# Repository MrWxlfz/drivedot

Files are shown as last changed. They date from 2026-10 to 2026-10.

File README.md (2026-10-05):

# DriveDot

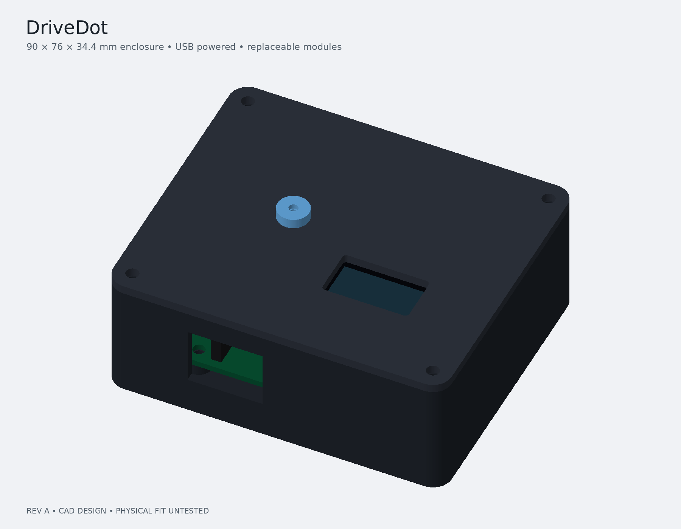
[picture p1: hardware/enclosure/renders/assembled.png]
DriveDot revision A enclosure render


*revision a CAD render — this hasn't been printed or built yet!!!!1*

a little dashboard gadget that tells you how smooth your driving is.

drivedot is an ESP32-S3 with an IMU and a tiny OLED. it reads acceleration, braking, and cornering, draws a live g-force dot on the screen, and gives you a summary when the drive ends. runs off usb, doesn't touch the car's electronics at all.

i'm learning to drive, so i wanted my first hardware project to be something i'd actually use. it's my warm-up project for hack club half-life.

## where it's at

revision a has an actual schematic, routed carrier pcb, printable case and firmware. i used ai to help create these files. the source, exports and checks are here so i can review them, make changes and build the prototype.

- **designed:** 60 × 40 mm, two-layer carrier pcb with XIAO sockets, screen/sensor headers and a button
- **modeled:** screw-fastened case, screen clamp, flat sensor cradle and button plunger
- **implemented:** standalone button controls, calibration, live display, session summary and usb csv
- **checked:** schematic/pcb rules and portable motion, button and calibration tests; see [validation](docs/validation.md)
- **still to do:** measure the real modules, confirm the full cost, print, solder, bench-test and record the results
- **planned:** a small ws2812 rgb led strip that goes green → yellow → red as the forces get harsher. it isn't on the revision a pcb or in the case cad yet, so it's not in the parts list

no physical fit test or road test yet, so no accuracy claims from me. the half life parts list is at about $63.99 for tier 2 ($65): digikey and amazon parts, pcbs from jlcpcb, the seven-part enclosure printed by jlc3dp in 9600 resin, screws from bolt depot, plus shipping, tariffs and a tax ceiling. bolt depot's shipping and soldering supplies aren't in that total, and tax and the final pcb order total are estimates until checkout. 9600 resin softens at about 56 °c, so the first print is a fit test only and not something to leave on a hot dash. nothing has been ordered yet. the parts research and pricing were done with claude.

## open the design

| what | files |
| --- | --- |
| schematic, routed board and fabrication exports | [KiCad project](hardware/pcb/README.md) |
| printable parts, editable CAD, STEP and renders | [enclosure](hardware/enclosure/README.md) |
| parts and required quantities | [selected parts](hardware/parts.md) · [planning BOM](hardware/bom.csv) |
| putting it together | [assembly guide](docs/assembly.md) · [wiring](hardware/wiring.md) |
| firmware and controls | [firmware setup](docs/firmware.md) |
| what's checked and what still needs testing | [validation](docs/validation.md) · [build plan](docs/build-plan.md) |

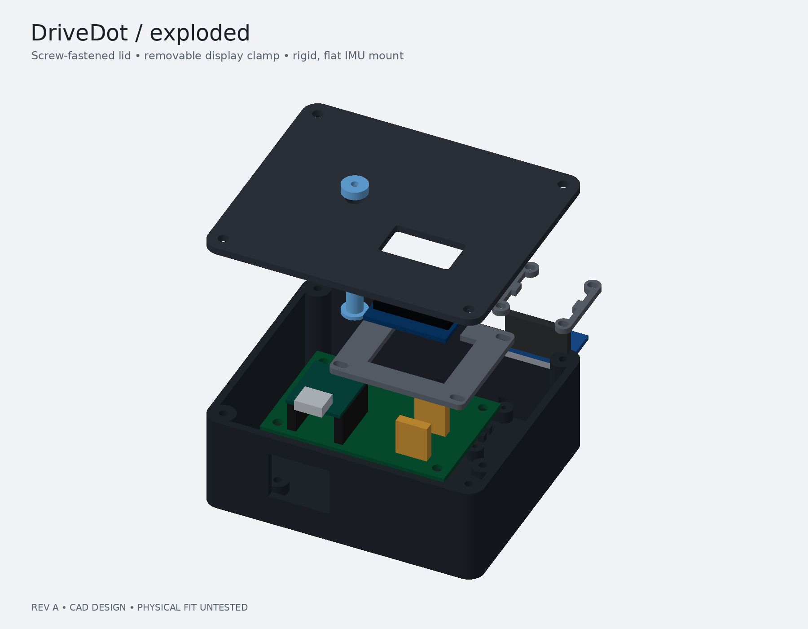
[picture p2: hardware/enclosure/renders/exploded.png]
DriveDot exploded CAD assembly


*exploded CAD view. the screen and sensor connect with short wires; their modeled envelopes still need checking against the received parts.*

## version 1

- Seeed Studio XIAO ESP32S3, GY-521 MPU6050 and 128 × 64 SSD1306 OLED
- hold the button for 1.5 seconds, then release to calibrate while parked and still
- short press/release to start or end a session
- live forward/lateral acceleration and a g-force dot
- summary with peak g and sustained-event counts
- csv over usb serial for checking the numbers

the score is a rough smoothness thing, not a safety grade. hills, bumps, sensor drift, and a shifted mounting angle all mess it up. check the summary while parked. the live feedback is really for a passenger during testing. mount it solid, flat, out of your line of sight and away from airbags.

## running it

1. read the [assembly guide](docs/assembly.md), [schematic notes](docs/first-schematic.md) and [wiring](hardware/wiring.md).
2. open `firmware/` in VS Code with PlatformIO. the selected board is `seeed_xiao_esp32s3`.
3. build and upload through the XIAO's USB-C port with a data cable:

```sh
cd firmware
pio run
pio run --target upload
pio device monitor
```

4. mount the sensor flat and keep it still. hold the button for 1.5 seconds and release when prompted. after calibration, tap to start and tap again to end.
5. serial commands also work: `c` calibrates, `n` starts and `e` ends. see [firmware setup](docs/firmware.md) for errors and limitations.

to run the logic tests without a microcontroller:

```sh
python3 scripts/test.py
```

## license

MIT. see [LICENSE](LICENSE).

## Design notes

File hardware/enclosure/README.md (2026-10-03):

# DriveDot enclosure — revision A

A dimensioned CAD design with seven printable solids, STEP files and generated images. **It has not been printed or physically fitted.** The checks in [validation.json](validation.json) cover the actual CAD/STL geometry against simplified electronic envelopes, not the dimensions of purchased modules.

Assembled CAD

Exploded CAD

The screw-fastened case holds the carrier on four standoffs. A removable frame clamps the OLED into the lid; separate edge clamps hold the IMU flat in the base. A guided plunger and separately screwed cap operate the PCB switch with a travel stop. OLED and IMU mounting holes are not assumed.

## Files and regeneration

- [Editable CadQuery source](../../scripts/generate_enclosure.py)
- [STEP assembly](step/drivedot-assembly.step); individual parts also in `step/`
- [Dimension drawing](dimensions.svg)
- [Body STL](stl/body.stl), [lid STL](stl/lid.stl), [plunger STL](stl/button-plunger.stl), [cap STL](stl/button-cap.stl), [OLED clamp STL](stl/oled-clamp.stl), [left IMU clamp STL](stl/imu-clamp-left.stl), [right IMU clamp STL](stl/imu-clamp-right.stl)
- [Validation report](validation.json)

STLs are already placed on the print bed. Lid and button cap are inverted; all others rest on their lowest flat face. STEP parts retain assembly coordinates. The generated `exports/` meshes are temporary renderer inputs and are omitted from published files.

With Python packages `cadquery==2.7.0`, `vtk`, `numpy` and `Pillow`, run from the repository root:

```sh
python scripts/generate_enclosure.py
```

The source exports CAD/meshes, checks solid validity, checks printed-part intersections and selected electronic keepouts, checks STL boundary/nonmanifold edges, and renders with a CPU depth buffer. No X server is needed. Case width/depth/height/lid thickness, OLED position/PCB size, and switch height are primary parameters. Other dimensions are recorded in the manifest or beside their CAD features. Changing the carrier layout, stack heights, module thicknesses or sensor orientation requires updating associated features and envelopes together. This is not a universal module adapter. The reference drawing must be revised after dimensional changes.

## Mechanical contract

All dimensions are mm. Origin: outside front-left corner; +Y toward the back, +Z upward. Front is the USB side. Vehicle installation must follow verified IMU axes, rather than assuming case axes equal sensor axes.

| Feature | Revision A geometry |
|---|---|
| Case envelope | 90 × 76 × 34.4; button cap reaches Z = 37.65, excluding screw head |
| Walls and floor | 2.4; outside corner radius 5 |
| Lid location | 2-deep lip, nominal 0.30 side gap |
| Lid screws | (5,5), (85,5), (85,71), (5,71); 3.4 clearance |
| Carrier | 60 × 40 × 1.6; lower-left (15,9), bottom Z = 6.0 |
| Carrier holes | (19,13), (71,13), (71,45), (19,45); 3.2 PCB holes |
| USB opening | X = 22…42, Z = 10…26, through front wall |
| OLED PCB | 27 × 25 × 1.6, centre (60,26), bottom Z = 27.6 |
| OLED glass assumption | 24.7 × 16.5 × 2.4, centred on PCB; top Z = 31.6 |
| Screen window | 23.0 × 13.2, centre (60,26); active area assumed 21.744 × 10.864 |
| OLED rear header | 10.16 × 2.54 × 12 downward keepout, centre (60,37.23), Z = 15.6…27.6 |
| IMU PCB | 20 × 15 × 1.6, centre (55,62), bottom Z = 4.8 |
| IMU header | 20.32 × 2.54 × 12 upward keepout, centre (55,55.77), starts Z = 6.4 |
| IMU solder tails | Trim to at most 2.2 below PCB (prefer 2.0); keepout Z = 2.6…4.8 |
| Switch | Centre (32,39); actuator nominally 5.0 above carrier top |
| Plunger | 5.2 shaft in 5.8 bore; 0.20 initial actuator gap |
| Travel stop | Cap stops after 0.45 downward travel, giving nominal 0.25 switch compression |

The XIAO socket plus male spacer is modelled as an 11.0-high stack, plus 1.2 board and 3.5 USB shell. Its top reaches Z = 23.3. **These are estimates:** allow at least 16 above the carrier and measure the purchased sockets, pins and USB plug. The access opening is deliberately broad. Connector and antenna geometry are not vendor CAD.

The OLED frame bears on a 1 mm PCB perimeter and four nominally clear 1.4 × 1.4 PCB corners. Its central rear notch clears the header and wire harness. Put the OLED header toward +Y; a front-facing tall header would clash with the carrier connectors. If this rotates the displayed image, configure firmware rotation after testing. Measure the actual active-area offset and glass envelope before printing the lid. The glass sits 0.4 below the lid; the PCB is held between stops and frame.

IMU clamps contact only 0.8 mm of each side at its middle, leaving the 8-pin header edge exposed. The four underside support pads are beneath these middle contacts, away from header solder. The header faces −Y in this model. Verify all board margins are free of components and solder before tightening; move the pads in CAD if necessary. Keep the IMU rigid and horizontal.

## Fasteners and printing

| Fastener | Quantity | Purpose |
|---|---:|---|
| M3 × 10 | 4 | Lid |
| M3 × 6 | 4 | Carrier |
| M2 × 6 | 4 | OLED clamp |
| M2 × 6 | 4 | IMU clamps |
| M2 × 6 | 1 | Button cap |

These are required fasteners, not sourced purchases or verified prices. Printed pilots are 2.6 for M3 and 1.7 for M2. Test a coupon and ream/tap to suit the printer and screws; hand-tighten into plastic. No inserts are required. Use pan or button heads; the holes have no countersinks. Screw heads are not included in CAD collision checks: measure their diameter and height, verify clearance to adjacent parts, and avoid heads that contact electronics.

Start a bench fit prototype with a 0.4 nozzle, 0.2 layers and at least three walls. The body prints upright; the lid and cap print outside face down. The USB roof needs a 20 mm bridge or removable support, and the cap has a shallow socket bridge. Inspect the slicer preview. Printer tolerance and material performance are untested. The slicer determines filament use and time.

Two underside 12 × 52 × 0.6 recesses accept suitable non-slip or fastening material. Select and test a secure mount outside sightlines and airbag paths. Select material for measured cabin temperatures; the design has no automotive environmental qualification.

## Assembly

1. Check prints and clear pilots. Confirm the plunger slides freely. Insert it into the lid from inside, fit the cap outside, and attach with one M2 × 6. Confirm its travel stop and release.
2. Seat the OLED display outward, with the header at the rear notch. Attach its clamp with four M2 × 6. Check the PCB corners seat on stops without loading the glass or components.
3. Seat the IMU on the four base supports. Check trimmed solder-tail clearance, header orientation and clamp contact margins. Attach both rails using four M2 × 6; the board must stay flat without rattling.
4. Mount the carrier with four M3 × 6, fit modules and route wires clear of the button guide. Leave enough slack to open the lid. Measure the actual switch height and adjust the plunger if it differs from 5.0.
5. Dry-fit the lid and test USB insertion and button release. Close with four M3 × 10 only after checking cable and component clearance. Verify sensor axis signs and calibrate on a level bench.

CAD checks do not simulate wires, screw heads, mechanical force, print tolerance, thermal performance or exact purchased electronics. Physical measurements and a bench fit remain required before treating this as a fabrication-ready design.

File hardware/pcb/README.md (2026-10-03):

# DriveDot carrier — revision A

This is an actual two-layer KiCad design with a routed PCB, schematic, Gerbers and drill files. It is **an unbuilt prototype design**. Electrical and design-rule checks pass; received-part fit, assembly, power-up and driving measurements have not been tested.

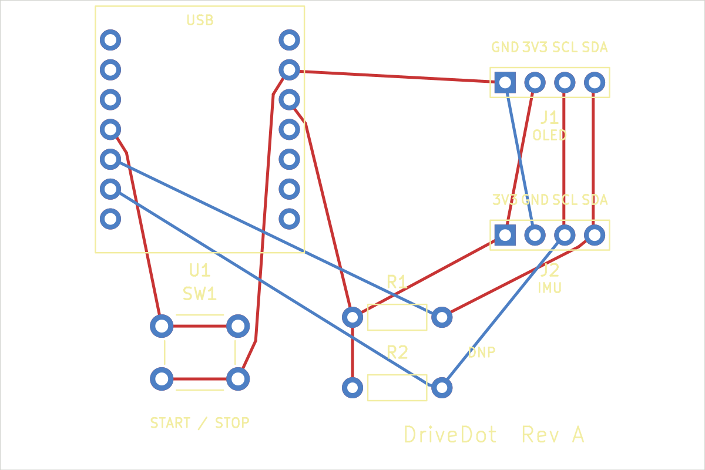
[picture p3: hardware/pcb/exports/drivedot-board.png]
DriveDot PCB: red front copper, blue back copper, yellow silkscreen


## Open the design

Open [`drivedot.kicad_pro`](drivedot.kicad_pro) in **KiCad 9**. The project-local symbols, footprints and library tables are included. There are no library downloads needed to edit this board.

- [Schematic PDF](exports/drivedot-schematic.pdf) · [schematic image](exports/drivedot-schematic.png)
- [Front copper preview](exports/drivedot-front.png) · [back copper preview, mirrored](exports/drivedot-back.png)
- [Schematic source](drivedot.kicad_sch) · [PCB source](drivedot.kicad_pcb)
- [Fabrication exports](fabrication/) · [fabrication ZIP](drivedot-rev-a-gerbers.zip)
- [ERC report](validation/erc.rpt) · [DRC and schematic-parity report](validation/drc.rpt)
- [Footprint evidence and license](SOURCES.md)

## Circuit and assembly

U1 holds the **standard Seeed XIAO ESP32S3**, USB facing the `USB` silkscreen. Solder two 1×7, 2.54 mm male headers to the XIAO and matching female sockets to the carrier. The 15.24 mm spacing between socket rows follows Seeed's official footprint. Socket mounting avoids pressing the XIAO's underside components against this carrier.

The display and GY-521 are mounted separately in the enclosure and joined with short insulated wires. J1 and J2 are **different power orders**. Their pin 1 pads are square. Viewed from the component side, pins increase left to right:

| Carrier pin | J1 → OLED | J2 → GY-521 |
| --- | --- | --- |
| 1 | GND | VCC / 3.3 V |
| 2 | VCC / 3.3 V | GND |
| 3 | SCL | SCL |
| 4 | SDA | SDA |

Connect the other end by the module's printed labels, including when a supplied header orientation differs. U1 D4/GPIO5 supplies SDA, D5/GPIO6 supplies SCL, and D3/GPIO4 reads SW1. Leave the sensor's AD0 low for address `0x68`; the OLED is expected at `0x3C`. The 5 V XIAO header pad is intentionally unconnected.

SW1 is a 6 mm tactile switch with 6.5 × 4.5 mm lead spacing. The two pads along each horizontal row are the same switch terminal. Confirm this with a continuity meter before soldering an alternate switch. Its actuator height must match the enclosure's adjustable button stem.

**R1 and R2 are optional 4.7 kΩ pull-ups and default to DNP (do not populate).** The footprints use 7.62 mm axial lead pitch. Selected modules may already contain pull-ups; adding another pair blindly changes the bus loading. Neither resistor is needed in the default carrier purchase list until the actual modules are inspected.

### Power-up checks

1. Unplug USB. Check socket orientation, continuity, absence of a 3.3 V-to-ground short, and all four harness wires against their labels.
2. Power the XIAO alone first, then connect the modules with USB unplugged. Power comes only from the XIAO USB-C port.
3. Measure the carrier 3.3 V rail and the GY-521's actual regulated sensor rail. The supplier lists 3.3 V VCC operation, but generic GY-521 regulator revisions vary. A dropout-prone module can undervolt the sensor; verify its rail against the actual regulator and MPU6050 specifications.
4. Check idle SDA/SCL voltages and the modules' pull-up supply rails. All bus signals must be compatible with the XIAO's 3.3 V logic. If the breakout revision is incompatible, change the module or design before using it; do not move J2 to 5 V by improvising a wire.
5. Run an I2C scanner, verify `0x68` and `0x3C`, then verify sensor axis directions and the button before closing the case.

Mount the IMU flat and rigidly: X forward, Y left, Z up. Calibration and vehicle motion testing still need to be done. This carrier has no connection to vehicle control or wiring.

## Mechanical interface

Coordinates are millimetres, viewed from above, origin at the carrier's USB-side left corner. Positive X runs right; positive Y runs away from the USB edge.

| Feature | Position / dimensions |
| --- | --- |
| Carrier | 60 × 40 × 1.6 mm |
| Non-plated mounting holes | Ø3.2 mm at (4,4), (56,4), (56,36), (4,36) |
| XIAO centre | (17,11), USB toward negative Y |
| XIAO board envelope | X 8.1–25.9; Y 0.5–21.5 mm |
| XIAO pin rows | X 9.38 / 24.62; first row Y 3.38; 2.54 mm pitch |
| J1 OLED | Pin 1 at (43,7); four pads along +X, 2.54 mm pitch |
| J2 IMU | Pin 1 at (43,20); four pads along +X, 2.54 mm pitch |
| SW1 actuator centre | (17,30) |
| R1 / R2 | Pin 1 at (30,27) / (30,33), 7.62 mm pitch along +X |

Allow up to **16 mm above the carrier** for an ordinary socket, male header, XIAO board and USB connector stack. This is a clearance allowance, not a measured supplied-part height. Check the actual header stack and cable moulding before printing a final enclosure. The USB shell extends approximately 1 mm beyond the carrier's Y=0 edge. The XIAO uses an external U.FL antenna connector; this firmware does not enable radio functions. There is no fictional on-board antenna keepout. If radio functionality is added, the external antenna must be placed and verified separately.

## Fabrication and validation

Suggested prototype fabrication settings: **two-layer FR-4, 1.6 mm, 1 oz copper**, ordinary solder mask, plated component holes and separate non-plated mounting holes. Board dimensions and hole type must be checked in the fabricator's viewer before ordering. The ZIP contains manufacturing files; it is not evidence of assembly or electrical operation.

KiCad **9.0.9** reports **0 ERC violations, 0 DRC violations, 0 unconnected items and 0 schematic-parity issues**, with warnings and exclusions included. No ERC or DRC issues are excluded. The four mechanical holes are intentionally board-only footprints. Tracks are 0.25 mm with a 0.20 mm minimum clearance. There are 30 plated component holes and 4 non-plated mounting holes; this layout needs no vias.

The generator and exports are reproducible:

```bash
/usr/bin/python3 scripts/generate_pcb.py
bash scripts/generate_pcb_exports.sh
```

Run from the repository root with KiCad 9's Python `pcbnew` module and CLI installed. The generator rebuilds sources and can overwrite manual CAD edits. Editing the committed KiCad files directly is also supported; rerun the export script after editing. It removes the previous fabrication ZIP before checking the design, and recreates the ZIP and validation hashes only after checks pass. Install the optional `cairosvg` Python package to refresh PNG previews in the same command; native SVG/PDF exports do not need it. PNG previews are rasterizations of the native SVG exports, not concept artwork. The supplied component and net names are checked against an exported schematic netlist before routing, and KiCad independently checks schematic/PCB parity afterward.

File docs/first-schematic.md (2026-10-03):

# Review the schematic

The revision A source and exports are in [hardware/pcb](../hardware/pcb/README.md). Open the supplied schematic in KiCad and follow these nets before assembling it.

| Net | Connections | Purpose |
| --- | --- | --- |
| +3V3 | XIAO 3V3 to both module connectors | Powers the selected 3.3V-compatible modules |
| GND | XIAO GND, both module connectors and button | Common return |
| SDA | XIAO D4 / GPIO5 to OLED and IMU SDA | I2C data |
| SCL | XIAO D5 / GPIO6 to OLED and IMU SCL | I2C clock |
| BUTTON | XIAO D3 / GPIO4 to normally-open button | Pulls low when pressed; firmware enables an internal pull-up |

The display and sensor connect with short wire harnesses. Their generic breakout footprints are not soldered directly to the carrier: received module sizes and pin orders can differ. Follow each connector's numbered pin labels and the actual breakout silkscreen. The OLED and IMU carrier connectors use different power-pin orders.

The GY-521's AD0 must be low for address `0x68`. Check its existing pull-down; wire AD0 to GND on the module if needed. Unused XDA, XCL and INT pins are left unconnected. The OLED is expected at `0x3C`.

Check both breakouts for I2C pull-ups and supply requirements. Pull-ups must reference 3.3V; do not add extra resistors without checking the combined resistance. Verify the GY-521's regulated sensor rail when supplied with 3.3V, since generic boards use different regulators. Do not compensate by feeding 5V to GPIO-connected pull-ups.

With power disconnected, use a meter to check that the switch closes GPIO4 to GND only when pressed. Check that 3V3 and GND are not shorted, and check each harness end-to-end before connecting it.

The CAD and electrical checks describe the design files. They do not verify soldering, received components or a physical prototype. Record what you inspect and change in your own journal, with the actual time spent.

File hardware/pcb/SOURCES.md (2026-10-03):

# Footprint evidence and authorship

Checked October 2, 2026. The schematic symbols, footprint graphics, routing generator and carrier design in this directory were created for DriveDot with AI assistance. They use the repository's MIT license. No supplier CAD artwork, logo, footprint file or 3D model is redistributed in this directory. Numerical dimensions and electrical connections are taken from the sources below; the vendor names identify compatible purchased parts.

| Source | Used to verify |
| --- | --- |
| [Seeed XIAO ESP32S3 documentation](https://wiki.seeedstudio.com/xiao_esp32s3_getting_started/) | D3/GPIO4, D4/GPIO5/SDA, D5/GPIO6/SCL; 3V3 regulated output; standard board envelope 21 × 17.8 mm; external antenna connector; header assembly |
| [Seeed official XIAO footprint archive](https://files.seeedstudio.com/wiki/XIAO-KiCad-Library/New_XIAO_Series_Footprints.zip), `XIAO-ESP32-S3-DIP.kicad_mod` | Fourteen through-hole centres at ±7.62 mm across rows, 2.54 mm along rows; physical numbering; USB orientation and approximate overhang |
| [ElectroPeak LCD-01-125 OLED](https://electropeak.com/0-96-inch-i2c-oled-display-module-ssd1306) | GND, VCC, SCL, SDA connector mapping; 3.3 V supply option. Module is wired off-board; no assumed module footprint is used |
| [ElectroPeak SEN-03-004 GY-521](https://electropeak.com/gyro-accelerometer-gy521-mpu6050) | VCC/GND/SCL/SDA roles, 3.3 V supply listing, default `0x68` address with AD0 low; listing itself flags generic-board revision variation |
| [Adafruit 367](https://www.adafruit.com/product/367), linked example 6 mm switch datasheet | Nominal 6 mm tactile body; 6.5 × 4.5 mm standard lead arrangement. Received-switch contact pairing and actuator height remain physical checks |
| [KiCad switch footprint source](https://gitlab.com/kicad/libraries/kicad-footprints/-/blob/master/Button_Switch_THT.pretty/SW_PUSH_6mm.kicad_mod) | Independent cross-check of the 6.5 × 4.5 mm pattern and horizontally paired duplicate switch terminals; footprint was redrawn, not copied |

The original Seeed footprint uses a 0.889 mm through-hole drill. DriveDot's independent socket carrier footprint deliberately uses 1.0 mm drills with 1.8 mm pads for standard 0.64 mm square socket leads. Header fit still requires a physical check. Generic off-board modules are connected by their printed labels because variant layouts and header orders differ.

DNP resistor and header footprints use standard 2.54/7.62 mm connector and axial lead pitches, not claims about an unselected vendor part. Matching sockets, wire and any optional resistors need final sourcing. The shared project budget remains unquoted for those items and for PCB delivery.

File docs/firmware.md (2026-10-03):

# Firmware notes

## Setup

Install PlatformIO through its VS Code extension or `python3 -m pip install platformio==6.1.18`. Open the `firmware` folder. The pinned PlatformIO environment targets the standard Seeed Studio XIAO ESP32S3 and uses its USB-C port for power, upload and native USB serial. The selected board manifest enables USB CDC at boot. Use a data-capable cable.

Other S3 variants, flash sizes or native-USB arrangements need matching board settings. Check the vendor documentation; don't copy a generic pin map onto a different board. Update `include/config.h` for different pins and I²C addresses. This selection uses D4/GPIO5 for SDA, D5/GPIO6 for SCL and D3/GPIO4 for the button. If upload cannot find the board, hold BOOT while connecting USB, release it, then retry; see the [manufacturer's guide](https://wiki.seeedstudio.com/xiao_esp32s3_getting_started/).

## Controls

| Input | Behavior |
| --- | --- |
| Hold button for 1.5 seconds, then release | When idle: calibrate after a short settling pause; keep the unit flat and stationary for about 2 seconds |
| Short button press and release | Start or end a session after calibration |
| Long hold during a session | Ignored; release does not end the session |
| Serial `c` | Same calibration while idle; ignored during a session |
| Serial `n` | Start a new session after calibration; ignored during an existing session |
| Serial `e` | End session and retain summary |

At power-up, the OLED prompts `PARK + MOUNT FLAT` / `Hold button 1.5s`. Hold until `RELEASE BUTTON`, release, and keep still. A successful calibration opens the ready screen. Tap to start, then tap to end and view the summary. No computer or serial command is required after uploading firmware.

Calibration is explicit, since power might be connected while the car is moving. Recalibrate while parked whenever you change the mount. A retry clears the previous calibration, so failure cannot silently reuse offsets from a different mounting position. Results are in RAM and disappear on restart.

The 100-sample calibration rejects nonfinite values, obvious motion on any acceleration axis, angular motion, zeroed data, an upside-down sensor and a substantially tilted mount. Defaults require acceleration magnitude 0.8–1.2 g, positive Z at least 0.8 g, horizontal magnitude no more than 0.35 g, gyro magnitude no more than 0.1 rad/s, and variance no more than 0.04 (m/s²)² on each axis. These are provisional bench thresholds, not proof that a vehicle is stationary. The check cannot reliably distinguish steady acceleration from tilt: calibrate only while parked.

The button uses 35 ms debouncing. A long hold consumes the release, preventing calibration from immediately starting a session. A short press acts on release.

## Measurement model

Subtract stationary X/Y offsets, convert m/s² to g using 9.80665, then apply a 120 ms low-pass filter. The baseline remains fixed during a drive so sustained acceleration isn't silently learned away. This is a first prototype: no gyroscope-based attitude compensation, GPS, speed measurement, automatic trip detection or cloud service.

This approach works best with a fixed, flat mounting orientation. Road grade and vehicle pitch/roll alter the gravity projection; changing tilt by hand can look like acceleration. The gyro is used only to help reject motion during calibration.

Events use provisional 0.30 g forward/braking and 0.35 g lateral thresholds, a 300 ms dwell and a 70% reset level. One held excursion produces one event. Smoothness is `100 × (1 − harsh_time / sampled_session_time)`, rounded to an integer. A score exists only after sampling; it isn't validated against driving skill or safety.

The sampling target is 50 Hz and display target 10 Hz, with I²C at 400 kHz. OLED/I²C transfers can lower the effective sampling rate; CSV timestamps are the evidence. Time deltas are taken after completed reads. Loop gaps over 200 ms are excluded from sampled session time and reset pending event dwell. A calibration sample gap over 100 ms rejects that attempt.

## Sensor errors

The pinned [Adafruit MPU6050 2.2.6 source](https://github.com/adafruit/Adafruit_MPU6050/blob/2.2.6/Adafruit_MPU6050.cpp) returns `true` from `getEvent()` even though its underlying burst read does not propagate an I²C error. DriveDot uses Adafruit initialization but reads the 14 sensor bytes directly through `Wire`, checking the address transaction and exact byte count. Conversion uses the selected ±4 g / ±500°/s scales. The range/filter configuration is read back at boot and before calibration.

A failed transaction stops an active session, prints its partial summary to serial, and leaves `SENSOR ERROR` on the OLED; check the connections and restart. This handles observable bus failures, not every sensor failure: a stuck sensor returning plausible bytes, changed configuration mid-session, or a disconnected display may not be detected. Hardware unplug/reconnect behavior has not yet been bench-tested.

CSV columns: `ms,forward_g,lateral_g,score,active`. A score of `-1` means no session samples have been recorded yet. Lines beginning with `#` are messages. When inactive the displayed score belongs to the last session, not current motion. No trip files are stored on-device.

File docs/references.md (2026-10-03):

# References

Primary references for the revision A design and selected hardware:

- [Seeed XIAO ESP32S3 pinout, power and CAD resources](https://wiki.seeedstudio.com/xiao_esp32s3_getting_started/)
- [PlatformIO XIAO ESP32S3 configuration](https://docs.platformio.org/en/latest/boards/espressif32/seeed_xiao_esp32s3.html)
- [Adafruit MPU6050 Arduino guide](https://learn.adafruit.com/mpu6050-6-dof-accelerometer-and-gyro/arduino)
- [Adafruit MPU6050 API](https://adafruit.github.io/Adafruit_MPU6050/html/class_adafruit___m_p_u6050.html)
- [Adafruit SSD1306 source and examples](https://github.com/adafruit/Adafruit_SSD1306)
- [KiCad documentation](https://docs.kicad.org/)
- [Hack Club hardware](https://hardware.hackclub.com/)

The Adafruit guide describes its own breakout. Generic modules need their own schematics and voltage checks. See [selected parts](../hardware/parts.md) for supplier listings and [PCB notes](../hardware/pcb/README.md) for dimensional sources. Funding details come from the user's project screenshot; event rules and eligibility still need checking on the event itself.

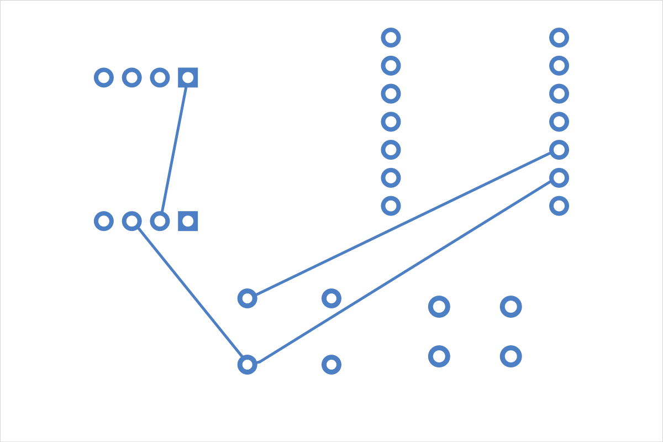
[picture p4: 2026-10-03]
hardware/pcb/exports/drivedot-back.png

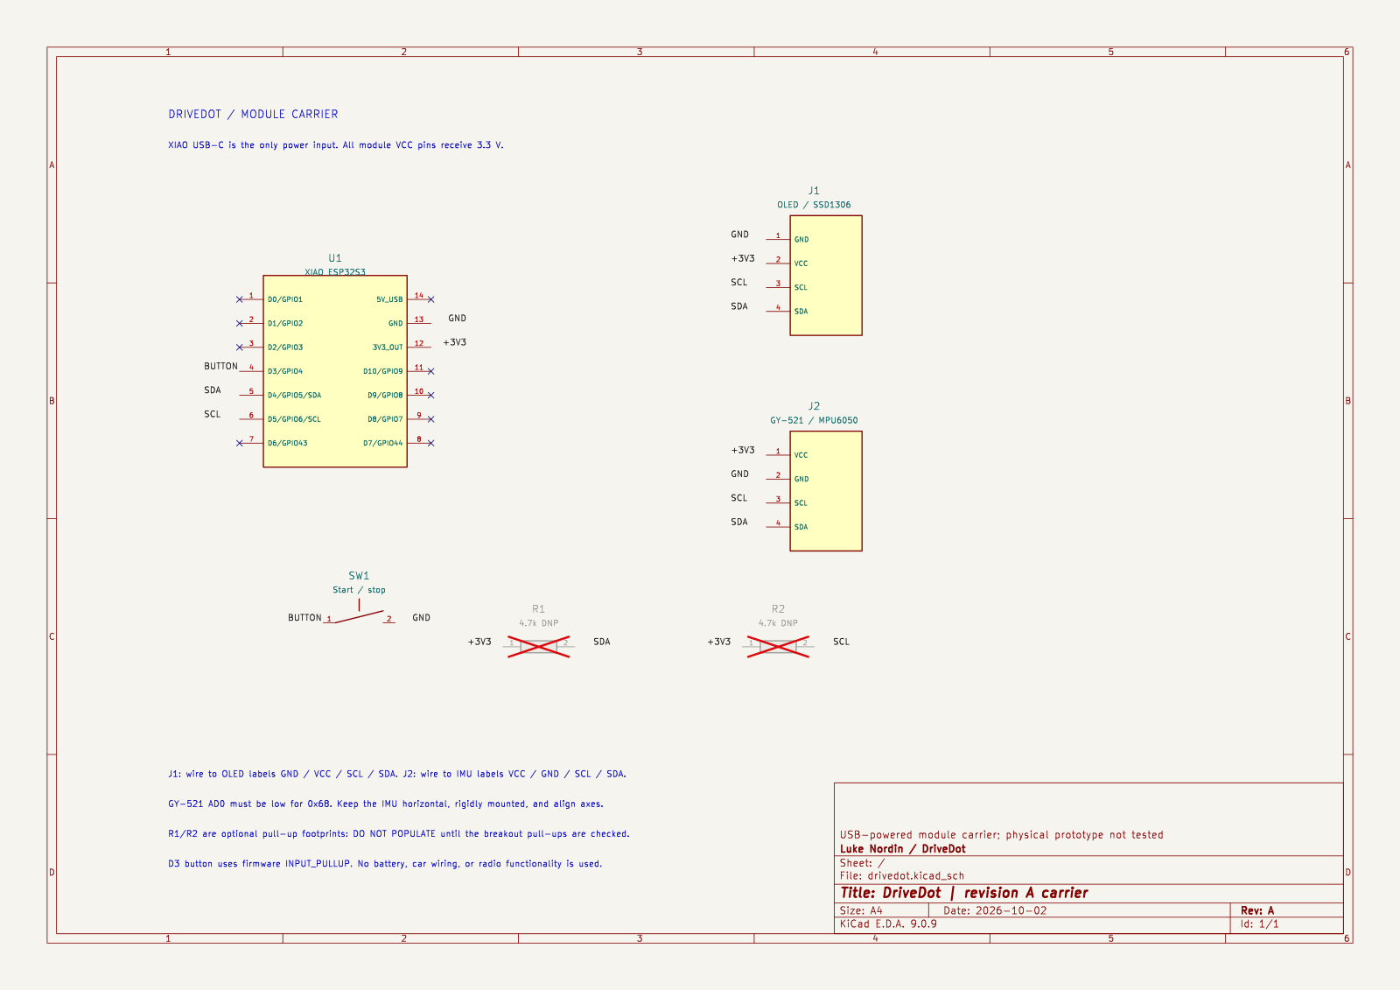
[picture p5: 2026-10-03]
hardware/pcb/exports/drivedot-schematic.png

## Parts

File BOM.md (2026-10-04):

# DriveDot — bill of materials

<!-- Generated by Half Life from project cmurr6oiu00zx01smbi1uyswa. Edits here are overwritten on the next sync. -->
<!-- Generated: 2026-10-04T16:18:33.363Z -->

> [!NOTE]
> This parts list is mirrored from [Half Life](https://halflife.hackclub.com). Editing it here will not change the platform's copy, and the next sync overwrites this file.

| Week | Tier | Parts funding |
| --- | --- | --- |
| Warm-up | Tier 1 | $30.00 |

| Part | What it's for | Qty | Unit | Total | Vendor |
| --- | --- | --- | --- | --- | --- |
| [USB-A to USB-C data cable, 1 m (Cvilux DH-20M50052)](https://www.digikey.com/en/products/detail/cvilux-usa/DH-20M50052/13177409) | Power and programming from the car's USB port | 1 | $1.80 | $1.80 | [DigiKey](https://www.digikey.com/en/products/detail/cvilux-usa/DH-20M50052/13177409) |
| [Seeed Studio XIAO ESP32S3 (113991114)](https://www.digikey.com/en/products/detail/seeed-technology-co-ltd/113991114/19285530) | Main controller (Wi-Fi/BLE ESP32-S3), plugs into the carrier PCB sockets | 1 | $7.49 | $7.49 | [DigiKey](https://www.digikey.com/en/products/detail/seeed-technology-co-ltd/113991114/19285530) |
| [C&K PTS645SL50-2 LFS tactile switch, 6x6 mm](https://www.digikey.com/en/products/detail/c-k/PTS645SL50-2-LFS/1146781) | Start/stop and calibration button on the carrier PCB | 1 | $0.28 | $0.28 | [DigiKey](https://www.digikey.com/en/products/detail/c-k/PTS645SL50-2-LFS/1146781) |
| [Sullins PPTC071LFBN-RC 7-pin female socket strip](https://www.digikey.com/en/products/detail/sullins-connector-solutions/PPTC071LFBN-RC/810146) | Two strips that the XIAO plugs into on the carrier PCB, so it is removable | 2 | $0.58 | $1.16 | [DigiKey](https://www.digikey.com/en/products/detail/sullins-connector-solutions/PPTC071LFBN-RC/810146) |
| [Sullins PRPC036SAAN-RC 36-pin male header strip](https://www.digikey.com/en/products/detail/sullins-connector-solutions/PRPC036SAAN-RC/2775218) | Cut to length for the XIAO pins and the OLED, IMU and carrier connectors | 1 | $0.65 | $0.65 | [DigiKey](https://www.digikey.com/en/products/detail/sullins-connector-solutions/PRPC036SAAN-RC/2775218) |
| [Adafruit 1951 female-to-female jumper wires, 3 in (20 pack)](https://www.digikey.com/en/products/detail/adafruit-industries-llc/1951/6827085) | Short wire harnesses from the carrier PCB to the OLED and the IMU module | 1 | $1.95 | $1.95 | [DigiKey](https://www.digikey.com/en/products/detail/adafruit-industries-llc/1951/6827085) |
| [3M 4026 double-sided mounting square, 3/4 in](https://www.digikey.com/en/products/detail/3m/4026-3-4-X3-4/1818870) | Sticks the enclosure to the dashboard | 2 | $0.36 | $0.72 | [DigiKey](https://www.digikey.com/en/products/detail/3m/4026-3-4-X3-4/1818870) |
| [0.96 in SSD1306 128x64 I2C OLED display module](https://www.amazon.com/dp/B0H6P6N3X7) | Live display: g-force dot, smoothness score and session summary (I2C address 0x3C) | 1 | $5.99 | $5.99 | [Amazon](https://www.amazon.com/dp/B0H6P6N3X7) |
| [GY-521 MPU6050 6-axis accelerometer/gyro module (2-pack)](https://www.amazon.com/dp/B0CYZ7BW1S) | Motion sensor that measures acceleration, braking and cornering (I2C address 0x68). One pack, second sensor is a spare | 1 | $7.98 | $7.98 | [Amazon](https://www.amazon.com/dp/B0CYZ7BW1S) |
| [Custom carrier PCB, 2-layer FR-4, 60 x 40 mm, 1.6 mm (min. order of 5)](https://cart.jlcpcb.com/quote) | Carries the XIAO sockets, OLED and IMU connectors and the button (Rev A gerbers in repo) | 1 | $4.00 | $4.00 | [JLCPCB](https://cart.jlcpcb.com/quote) |
| [BTF-Lighting WS2812B RGB LED strip, 5V, 60 LED/m, 3.28 ft](https://www.amazon.com/dp/B088BRY2SH) | Smoothness light that goes green to yellow to red as forces get harsher (planned add-on, a short cut length is used) | 1 | $7.99 | $7.99 | [Amazon](https://www.amazon.com/dp/B088BRY2SH) |
| **Parts subtotal** | — | — | — | **$40.01** | — |
| **Tax & shipping** | — | — | — | **$16.56** | — |
| **Total** | — | — | — | **$56.57** | — |

**$26.57 over the tier's funding.** Every tier gives a fixed amount for parts, so this needs cutting back or a higher tier.

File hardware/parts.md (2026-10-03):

# Selected parts

Supplier listings checked October 2, 2026. No orders have been placed.

| Part | Exact selection | Buy quantity | Listed USD price | Supplier |
| --- | --- | --- | --- | --- |
| Controller | Seeed Studio XIAO ESP32S3, SKU 113991114, standard unsoldered 1pcs | 1 | $7.49 | [Seeed](https://www.seeedstudio.com/XIAO-ESP32S3-p-5627.html) |
| Motion sensor | GY-521 MPU6050, SEN-03-004 | 1 | $1.96 | [ElectroPeak](https://electropeak.com/gyro-accelerometer-gy521-mpu6050) |
| Screen | 0.96-inch SSD1306 I2C OLED, LCD-01-125; white option preferred | 1 | $1.29 base listing | [ElectroPeak](https://electropeak.com/0-96-inch-i2c-oled-display-module-ssd1306) |
| Button | 6mm through-hole tactile switch, Adafruit product 367 | 1 pack of 20 | $2.50 for the whole pack | [Adafruit](https://www.adafruit.com/product/367) |

These four listings total **$13.24 before shipping, tax or import charges**. Screen option pricing must be confirmed. The full button pack is counted, not a fictional one-button checkout price. If a suitable button is already available or can be bought from another selected supplier, replace that line with the real source and price to avoid a third shipment.

## Budget check

The four core listings total **$13.24**, leaving **$16.76 of a $30 budget** before the carrier, connectors, fasteners, printing, cable, shipping and tax. That remaining amount is not an approved or quoted budget.

Revision A also needs two 1x7 XIAO socket strips, mating male headers, two 1x4 carrier headers, two short four-wire module harnesses, the printed part set, four M3x10 screws, four M3x6 screws and nine M2x6 screws. The exact head types and print details are in the [enclosure guide](enclosure/README.md). Count any supplied or already-owned parts before buying duplicates. The [planning CSV](bom.csv) separates these required quantities from the four priced listings; unquoted cells are intentionally blank.

**The complete Tier 1 budget is not verified.** Previous generic allowances are not supplier quotes for this finished design. Confirm checkout totals and fabrication pricing, including minimum order and pack quantities. Shipping from multiple suppliers may require consolidated sourcing or available supplies to meet the target.

## Why this controller

The XIAO has a compact form factor and a documented pinout and KiCad resources. The firmware now selects `seeed_xiao_esp32s3` and uses D4/GPIO5 for SDA, D5/GPIO6 for SCL and D3/GPIO4 for the button. It replaces the generic DevKitC configuration in the starter.

- [Seeed pinout, power details and CAD resources](https://wiki.seeedstudio.com/xiao_esp32s3_getting_started/)
- [PlatformIO XIAO ESP32S3 board](https://docs.platformio.org/en/latest/boards/espressif32/seeed_xiao_esp32s3.html)

Version 1 remains USB powered. It does not need a battery, Grove base, camera expansion board or RGB strip.

## Before ordering revision A

The carrier uses socket/header footprints, with wired connections to the generic breakouts. Use the module schematics and received board markings. Keep I2C at 3.3V, inspect the GY-521 regulator and pull-ups, check OLED address and pin order, and measure headers and mounting holes. Cheap generic breakouts can differ between batches. Supplier dimensional claims are starting points, not a completed mechanical fit check.

## Half-Life parts entry

Add actual selected purchases to the project's parts form with their vendor URLs and full purchase quantities. Enter shipping/tax separately from checkout quotes. `hardware/bom.csv` is a planning sheet; the event's synced root `BOM.md` should remain managed by the event.

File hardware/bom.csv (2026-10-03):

item | quantity | unit_usd | total_usd | specification | supplier_url | price_status
Seeed Studio XIAO ESP32S3 SKU 113991114 | 1 | 7.49 | 7.49 | standard unsoldered 1pcs version; USB-C; not Sense or Plus | https://www.seeedstudio.com/XIAO-ESP32S3-p-5627.html | listed USD price checked 2026-10-02; checkout not quoted
GY-521 MPU6050 ElectroPeak SEN-03-004 | 1 | 1.96 | 1.96 | I2C; VCC at 3.3V; verify received module | https://electropeak.com/gyro-accelerometer-gy521-mpu6050 | listed USD price checked 2026-10-02; checkout not quoted
SSD1306 I2C OLED ElectroPeak LCD-01-125 | 1 | 1.29 | 1.29 | 128x64; 4-pin I2C; request white option; confirm selected variant price | https://electropeak.com/0-96-inch-i2c-oled-display-module-ssd1306 | listed base USD price checked 2026-10-02; variant checkout not quoted
Adafruit 367 tactile button 20-pack | 1 | 2.50 | 2.50 | one full 20-pack purchase; use one button; 6mm through-hole | https://www.adafruit.com/product/367 | listed USD pack price checked 2026-10-02; checkout not quoted
Optional I2C pull-up resistors R1 R2 | 2 |  |  | 4.7k axial; 7.62mm lead spacing; DO NOT POPULATE unless measured breakout pull-ups require these |  | optional DNP; not included in core parts subtotal
XIAO socket strips | 2 |  |  | 1x7 female 2.54mm pitch; selected stack height must match enclosure |  | unquoted; supplier and purchase pack size pending
XIAO male header strips | 2 |  |  | 1x7 male 2.54mm pitch; may be included with XIAO; verify before buying |  | unquoted; supplier and purchase pack size pending
Carrier module headers | 2 |  |  | 1x4 male 2.54mm pitch for J1 and J2 |  | unquoted; supplier and purchase pack size pending
Module wire harnesses | 2 |  |  | 4 conductors each; 2.54mm mating ends; verify each module pin order; short insulated wires |  | unquoted; supplier and purchase pack size pending
Module male headers | 1 |  |  | OLED 1x4 and GY-521 1x8 if not supplied or pre-soldered; verify exact received modules |  | unquoted; supplier and purchase pack size pending
Carrier PCB fabrication | 1 |  |  | 60x40mm revision A; quote fabrication minimum quantity and delivery |  | unquoted; supplier and purchase pack size pending
Printed enclosure set | 1 |  |  | See hardware/enclosure README for complete STL set; material and printer access unquoted |  | unquoted; supplier and purchase pack size pending
M3x10 lid screws | 4 |  |  | See enclosure guide for head type and pilot requirements |  | unquoted; supplier and purchase pack size pending
M3x6 carrier screws | 4 |  |  | See enclosure guide; verify screw length against PCB and standoffs |  | unquoted; supplier and purchase pack size pending
M2x6 internal screws | 9 |  |  | 4 OLED clamp; 4 IMU clamps; 1 button cap; verify actual engagement |  | unquoted; supplier and purchase pack size pending
Non-slip pads and mounting supplies | 1 |  |  | Optional pads do not substitute for secure level mounting; dimensions in enclosure guide |  | unquoted; supplier and purchase pack size pending
USB-C data cable | 1 |  |  | Verify existing cable before purchasing; USB shell fit must match enclosure opening |  | unquoted; supplier and purchase pack size pending
Shipping tax and import charges | 1 |  |  | Unknown; requires all supplier checkout quotes; not zero |  | unquoted; supplier and purchase pack size pending

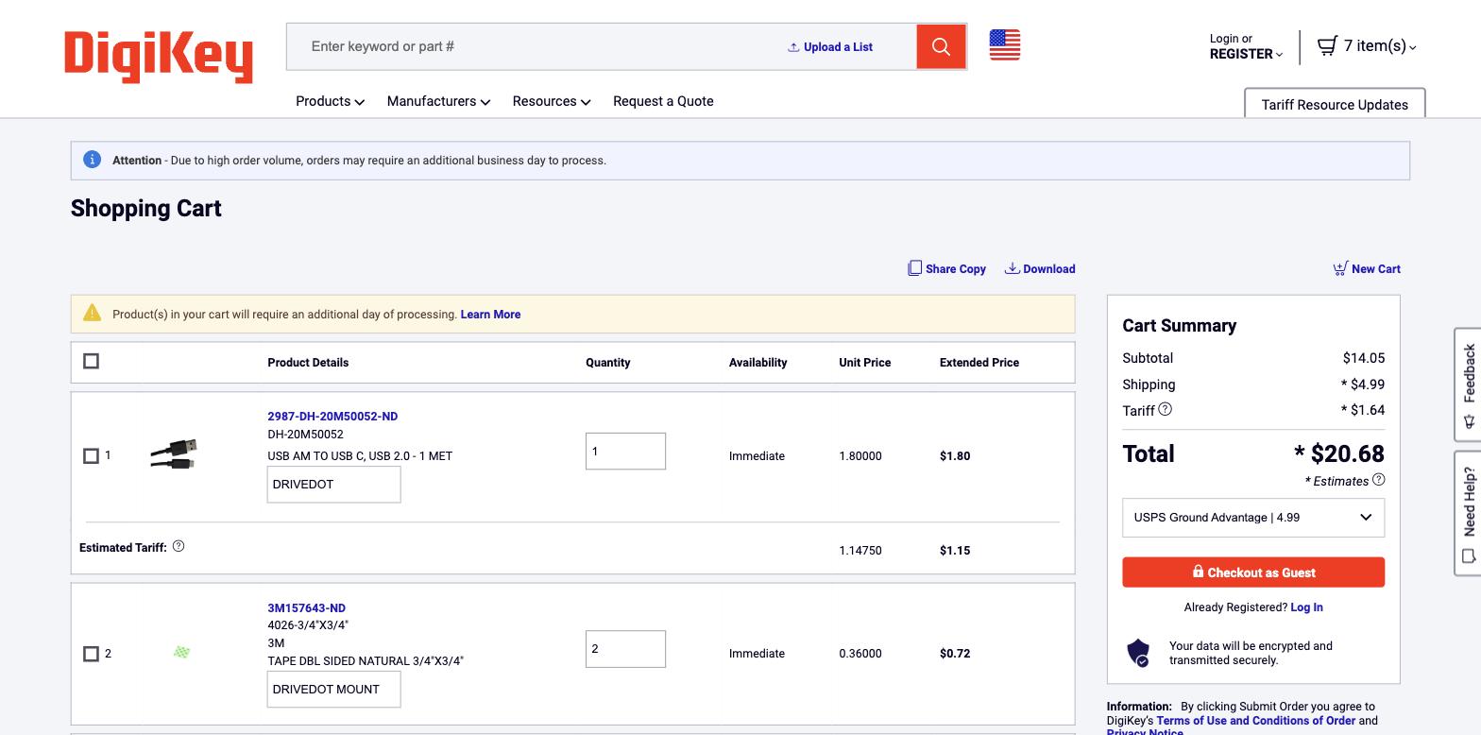
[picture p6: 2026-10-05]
docs/sourcing/04-digikey-cart.jpg

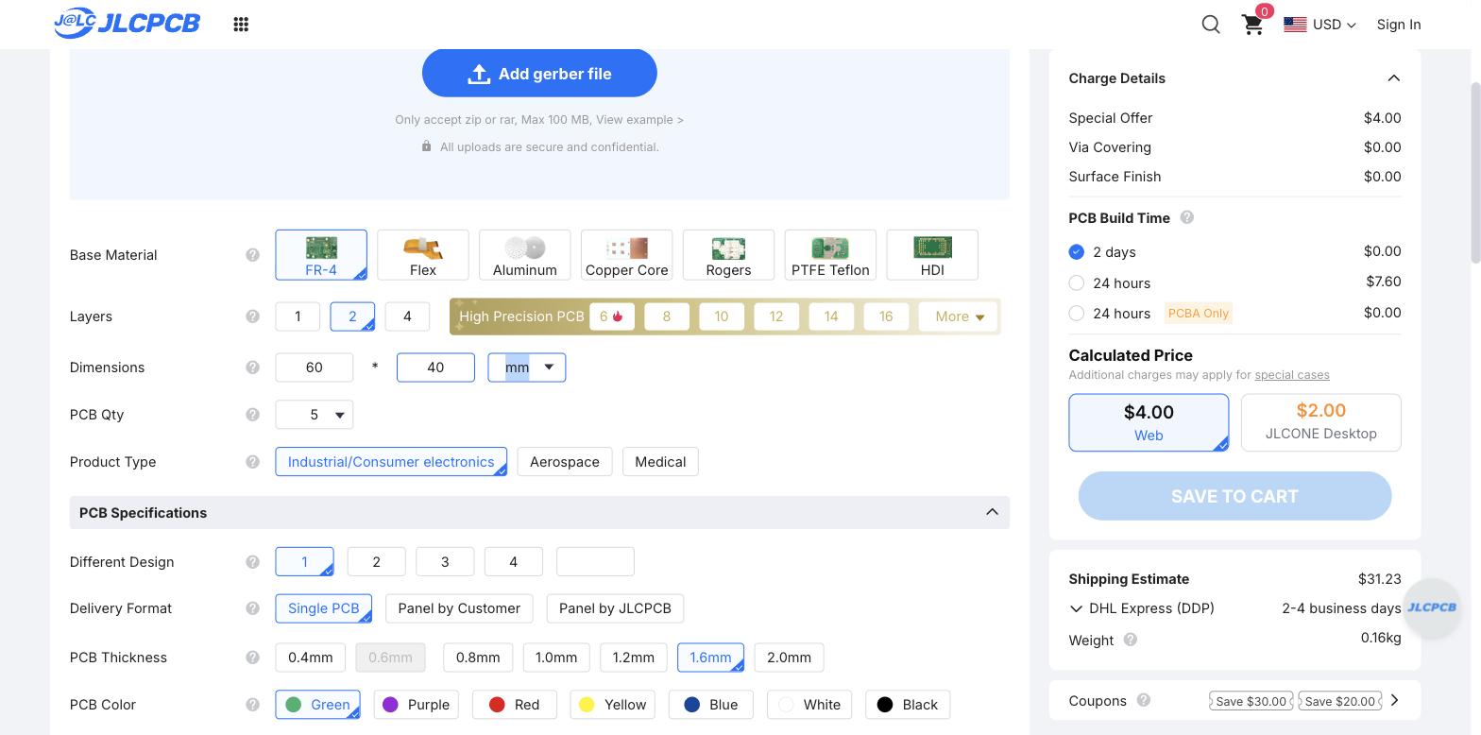
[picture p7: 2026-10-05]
docs/sourcing/02-jlcpcb-pcb-quote.jpg

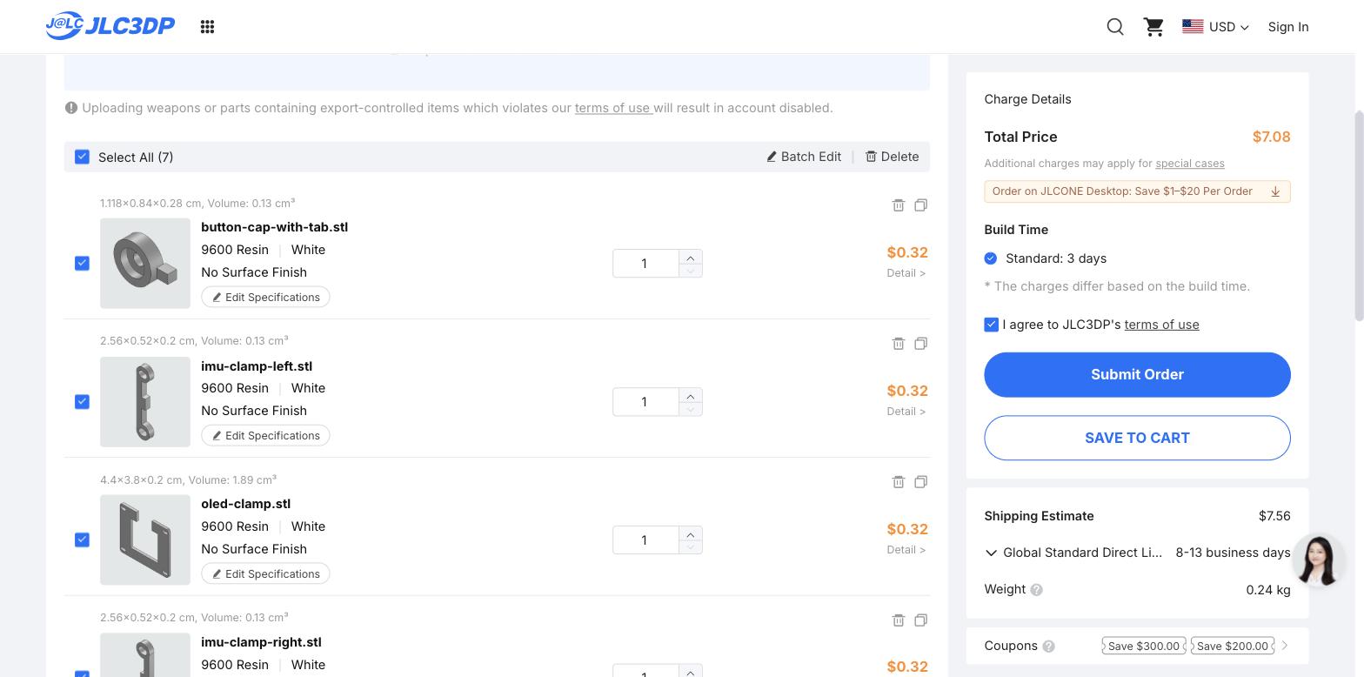
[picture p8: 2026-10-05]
docs/sourcing/01-jlc3dp-enclosure-quote.jpg

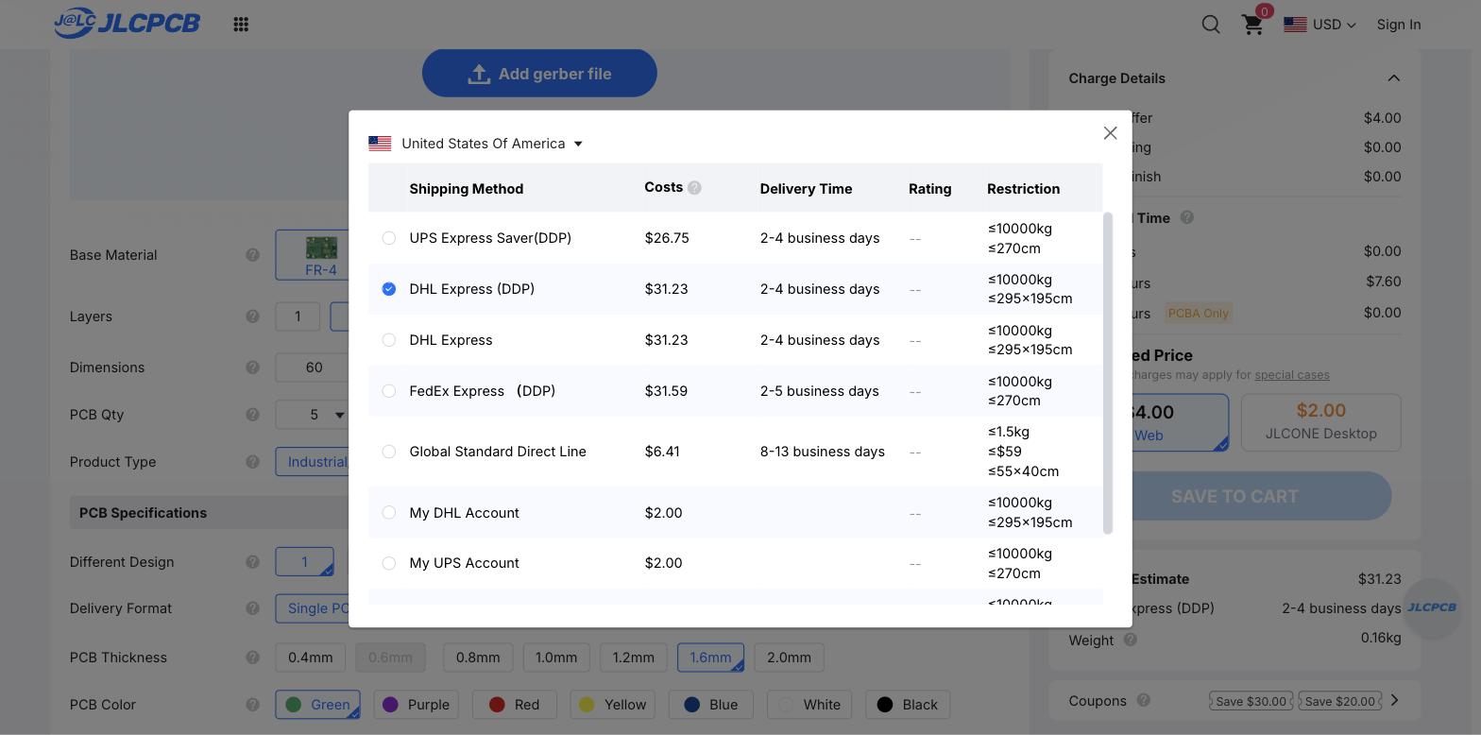
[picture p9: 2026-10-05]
docs/sourcing/03-jlcpcb-shipping-options.jpg

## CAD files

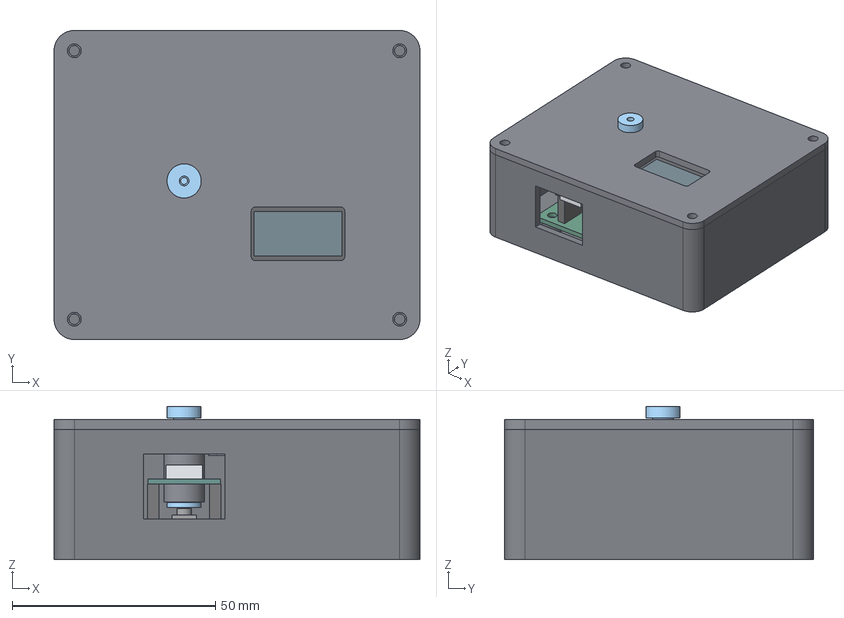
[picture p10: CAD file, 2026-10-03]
hardware/enclosure/step/drivedot-assembly.step
90.0 x 76.0 x 37.6 mm
lid
button-plunger
button-cap
oled-clamp
imu-clamp-left
imu-clamp-right
carrier-pcb
xiao-pcb
usb-envelope
xiao-sockets
connector-keepouts
tactile-switch
oled-pcb
oled-glass
oled-active-area
imu-pcb
imu-chip
imu-header-keepout
imu-header-tails
oled-header-keepout

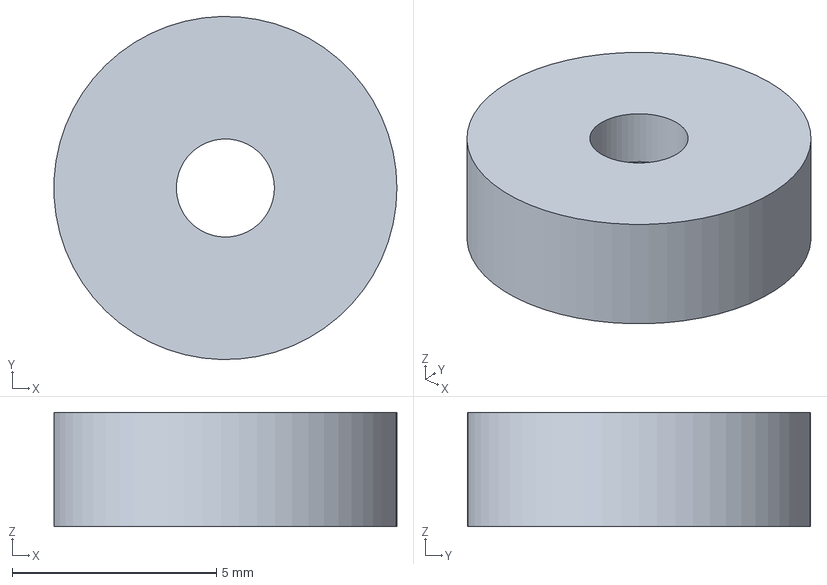
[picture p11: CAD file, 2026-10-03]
hardware/enclosure/step/button-cap.step
8.39 x 8.40 x 2.80 mm

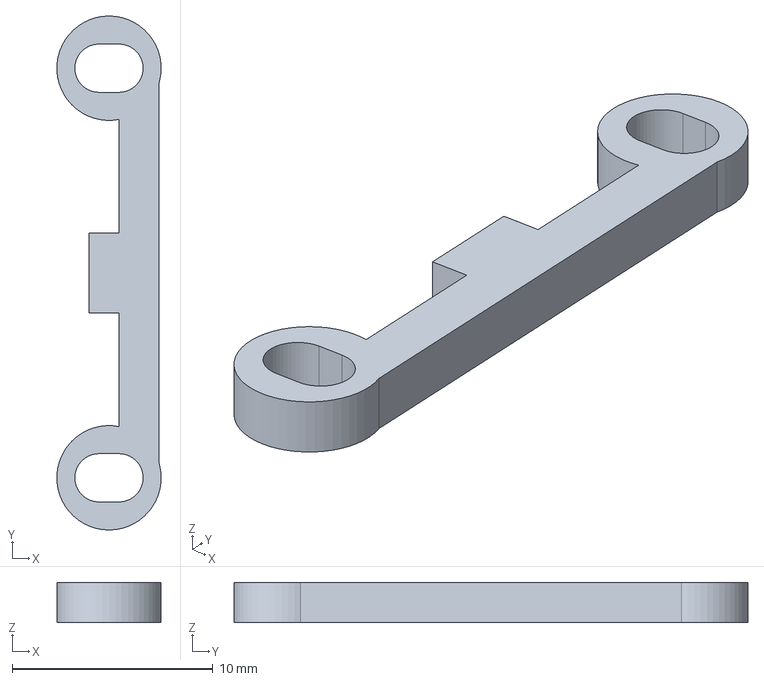
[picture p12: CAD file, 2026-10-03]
hardware/enclosure/step/imu-clamp-right.step
5.20 x 25.6 x 2.00 mm

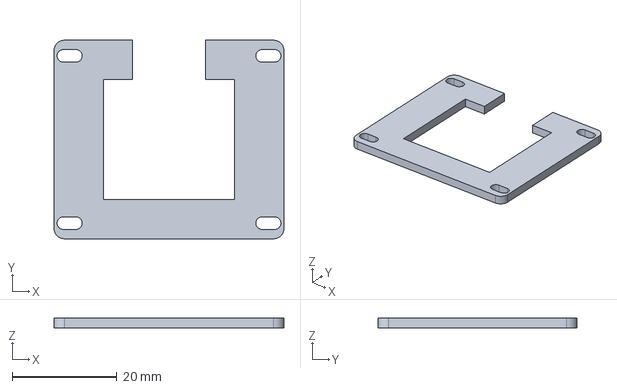
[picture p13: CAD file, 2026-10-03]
hardware/enclosure/step/oled-clamp.step
44.0 x 38.0 x 2.00 mm

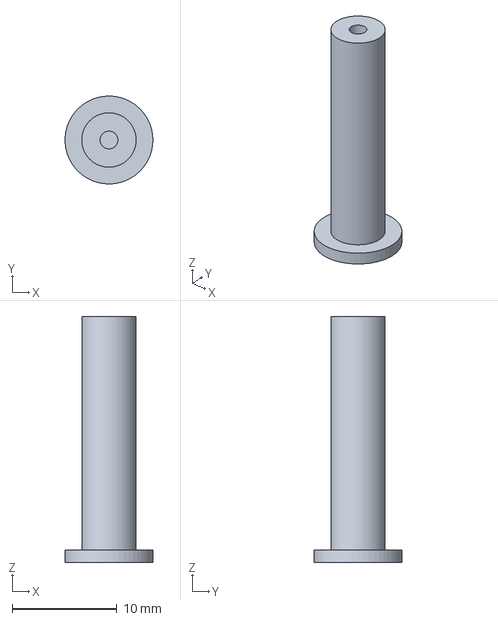
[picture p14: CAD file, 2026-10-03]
hardware/enclosure/step/button-plunger.step
8.39 x 8.40 x 23.5 mm

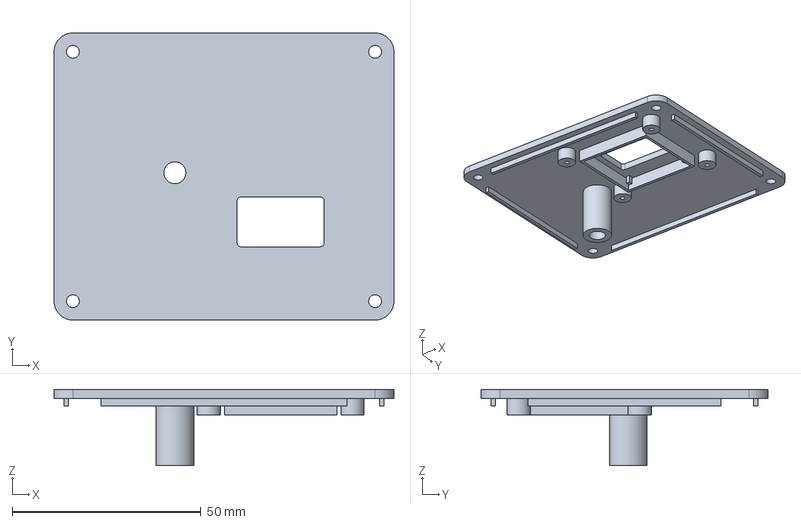
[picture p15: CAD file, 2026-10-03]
hardware/enclosure/step/lid.step
90.0 x 76.0 x 20.2 mm

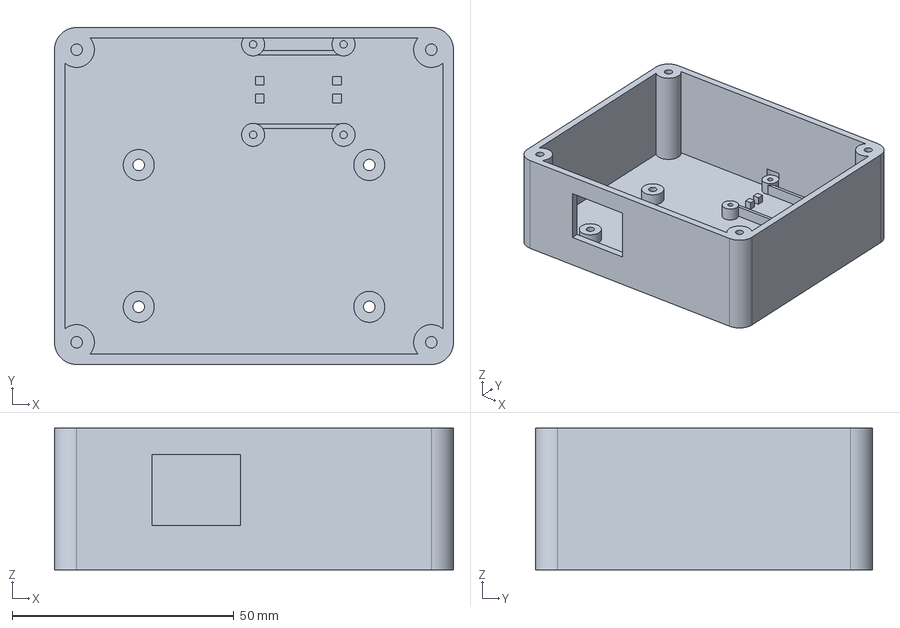
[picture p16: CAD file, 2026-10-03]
hardware/enclosure/step/body.step
90.0 x 76.0 x 32.0 mm

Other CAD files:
hardware/enclosure/step/imu-clamp-left.step
hardware/enclosure/stl/body.stl
hardware/enclosure/stl/button-cap.stl
hardware/enclosure/stl/button-plunger.stl
hardware/enclosure/stl/imu-clamp-left.stl
hardware/enclosure/stl/imu-clamp-right.stl
hardware/enclosure/stl/lid.stl
hardware/enclosure/stl/oled-clamp.stl

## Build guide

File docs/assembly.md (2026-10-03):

# Revision A assembly

This is an unbuilt prototype design. Use the [PCB notes](../hardware/pcb/README.md) and [enclosure notes](../hardware/enclosure/README.md) for the exact sources, fabrication settings, fasteners and dimensional assumptions.

## 1. Check the modules

Use the standard XIAO ESP32S3, a GY-521 MPU6050 and a four-pin I2C SSD1306 display. Confirm the actual voltage requirements, pin labels and dimensions. Measure the OLED glass as well as its PCB; the case must not press on the glass. Check the switch's joined leg pairs with a meter.

The carrier is 60 × 40 mm. Its four mounting holes are at `(4,4)`, `(56,4)`, `(56,36)` and `(4,36)` mm from the PCB drawing origin. Keep the XIAO USB connector facing the marked board edge. The screen and IMU are mounted separately and connect with wire harnesses.

## 2. Assemble the carrier

With USB disconnected, solder the sockets, module connectors and switch using the placement drawing. Keep sockets square and check the XIAO orientation before inserting it. Leave the optional R1/R2 pull-up footprints empty until the breakout pull-ups have been checked. Inspect solder joints and measure for a 3V3-to-GND short.

Make the two harnesses by net name. **Do not assume both connectors have the same pin order.** The carrier OLED connector is GND, 3V3, SCL, SDA; the IMU connector is 3V3, GND, SCL, SDA. Check every wire end-to-end against the labels on the received modules. Keep wiring short and clear of screw bosses and the moving button.

## 3. Bring it up on the bench

Use a known USB data cable and follow [firmware setup](firmware.md). First confirm power, then display and IMU communication. Disconnect power immediately if a part becomes hot. If a module is absent or a read fails, fix the wiring before starting a session.

Keep the IMU rigid and flat, with sensor X forward, sensor Y left and sensor Z up. Verify the chip axes against its documentation and motion data; the PCB arrow on a generic module is not sufficient. The firmware uses a fixed mounting frame and does not compensate for arbitrary sensor tilt. Its sign settings can reverse X/Y directions but cannot swap the two axes. The rectangular IMU cradle does not allow a 90-degree module rotation: orient the whole case to suit the sensor, or revise the cradle/firmware axis mapping before fabrication.

Hold the button for 1.5 seconds while idle and still to calibrate. Release it after the hold; that release should not start a session. A short press/release starts or ends a session. Inspect USB CSV readings at rest and during gentle movements before enclosing the device.

## 4. Fit the enclosure

Print the separate parts in the orientations described in the [enclosure guide](../hardware/enclosure/README.md). Dry-fit without electronics first. Clear the screw holes and check lid registration. The plunger assumes a switch actuator 5.0 mm above the carrier; measure yours and adjust the CAD if needed. Insert the plunger from inside the lid, fit its separate cap outside, and secure it with one M2 × 6 screw. Check free movement, release and the cap's travel stop.

Install the carrier and seat the IMU flat in its cradle, with its header toward the USB side (−Y). Trim IMU solder tails to at most 2.2 mm below the PCB, preferably 2.0 mm. Fit the OLED with its header toward the rear (+Y), through the clamp's notch; a tall front-facing header would hit the carrier connectors. Configure display rotation in the firmware if this orientation turns the image upside down. Tighten the clamps only enough to retain the boards, route wires clear of the plunger, and verify USB access and button return before closing the lid.

Use the specified screw lengths. A screw that is too long can hit a PCB or crack a printed boss. Do not substitute lengths blindly. The mounting surface must keep the sensor level; an angled dashboard needs a separate leveling mount, which is not included in this revision.

## 5. Record the result

Repeat calibration and button tests with the case closed, take photos and record the actual findings. Inspect heat and mounting stability before any vehicle test. Calibrate and review the summary while parked; use a passenger for observing live feedback during testing. This prototype's score is a rough motion metric, not a safety grade.

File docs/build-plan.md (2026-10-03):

# Build plan

Revision A includes a carrier PCB, enclosure and standalone firmware. Start with [the assembly guide](assembly.md), [PCB files](../hardware/pcb/README.md) and [enclosure files](../hardware/enclosure/README.md).

## Before ordering or printing

1. Review the schematic and check the selected module pinouts.
2. Confirm supplier checkout totals, fabrication minimum quantities, shipping and tax. The $30 total is still unverified.
3. Measure the received XIAO headers/USB connector, OLED glass and board, GY-521 board, switch and fasteners. Update the CAD parameters where needed.
4. Inspect the fabrication and CAD checks, then review Gerbers in the manufacturer's viewer and STLs in a slicer.

## Bench prototype

1. Test the modules with short wires before committing the assembly to the case.
2. Compile and upload the firmware; check stationary readings over USB serial.
3. Hold the button to calibrate while still, then short-press to start and end a session.
4. Test a straight push and stop, then sideways motion. Verify sensor axes and signs using recorded data.
5. Test button debounce, sensor failure handling and recalibration. Change wiring only with power disconnected.
6. Fit the parts, verify plunger travel and connector clearance, then repeat the stationary test in the closed enclosure.

## Evidence still needed

- [ ] Received module measurements and physical fit check.
- [ ] Exact purchased parts, fabrication and checkout totals.
- [ ] Assembled PCB power and continuity checks.
- [ ] Firmware upload and real sensor/display/button results.
- [ ] Calibration and motion recordings.
- [ ] Photos, demo and journal with actual work time.
- [ ] Event eligibility, AI-assistance rules, deadline timezone and submission requirements checked.

The source and exports were created with AI assistance. Automated checks and rendered views are design evidence, not photographs or proof of a built device. The event's synced `BOM.md` and `JOURNAL.md` remain managed by Half-Life; log only real work and purchases there.

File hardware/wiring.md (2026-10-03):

# Prototype wiring

Unplug USB before wiring. These pins target the standard **Seeed Studio XIAO ESP32S3**, not the original DevKitC draft or a bare module. Confirm the exact board and module schematics before powering up. ESP32 GPIO is 3.3 V logic.

| XIAO ESP32S3 connection | Destination |
| --- | --- |
| 3V3 | MPU6050 and OLED supply inputs, only if each selected breakout supports 3.3 V power |
| GND | MPU6050 GND, OLED GND, one side of button |
| D4 / GPIO5 | MPU6050 SDA and OLED SDA |
| D5 / GPIO6 | MPU6050 SCL and OLED SCL |
| D3 / GPIO4 | Other side of button; firmware enables internal pull-up |
| USB-C connector | USB power, firmware upload and native USB serial |

Selected modules: ElectroPeak GY-521 `SEN-03-004` and SSD1306 I²C OLED `LCD-01-125`. Use the module pin labels, not an assumed left-to-right pin order. The display vendor lists GND/VCC/SCL/SDA. See [the sourced parts](parts.md).

Expected addresses: MPU6050 `0x68` (AD0 low), OLED `0x3C`. Adjust `firmware/include/config.h` to match the actual modules. Leave unused IMU interrupt and auxiliary pins unconnected unless the selected breakout documentation says otherwise.

I²C pull-ups must go to 3.3 V. Inspect breakout schematics for existing pull-ups; add a suitable pair (start with 4.7 kΩ) only if needed. A regulator on a breakout does not establish that its I²C pins are safe at every supply voltage.

Mount the IMU horizontally and rigidly: sensor X toward the front of the vehicle, sensor Y to the left, Z up. The display and enclosure may be angled independently. Check the manufacturer's axis diagram, then verify signs with bench motion. An IMU attached directly to an angled face would need coordinate rotation that this starter does not implement.

For the four-leg tactile button, use one leg from each electrically separate side; confirm with a continuity meter. Legs permanently connected inside the switch must not be mistaken for the switched contact pair.

Version 1 uses the XIAO's existing power circuit. Do not add a second USB supply in parallel or connect to car wiring. The optional RGB indicator is not wired or supported by this starter firmware yet.

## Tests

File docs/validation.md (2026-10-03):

# Validation

## Automated

`python3 scripts/test.py` builds two portable C++ test programs:

- Motion: stationary offset subtraction, signed braking/acceleration, one event per sustained excursion, left/right turns, rejection of brief gate spikes, session reset, invalid samples, lost-time dwell reset, calibration guards and score behavior across different durations.
- Controls/calibration: contact bounce, short press, 1.5-second hold, one action per hold, release suppression, delayed input polling, `millis()` rollover, calibration sample count, offsets, invalid numbers, zeroed data, upside-down/tilted mounting, angular motion and Z-axis shaking.

Both programs pass on the host compiler with `-Wall -Wextra -Werror` (2026-10-03 UTC).

`python3 -m platformio run -d firmware` also passes locally for `seeed_xiao_esp32s3` using the pinned dependencies (2026-10-03 UTC). The resulting build uses 19,032 bytes RAM and 300,017 bytes flash. This verifies compilation and linking, including the direct `Wire` acquisition and OLED APIs. The firmware has not been flashed to or tested on a physical board.

These are synthetic logic tests and a cross-compile. They do not validate electrical wiring, I²C bus-fault behavior, real sensor noise, the calibration thresholds on hardware, physical orientation, or real driving accuracy. The GitHub workflow repeats the host tests and ESP32 build; its own run status must be checked separately.

## Hardware design checks

KiCad 9.0.9 reports **0 ERC violations, 0 DRC violations, 0 unconnected items and 0 schematic/PCB parity issues**, with no exclusions. See the [ERC report](../hardware/pcb/validation/erc.rpt), [DRC report](../hardware/pcb/validation/drc.rpt) and [validation summary](../hardware/pcb/validation/summary.json). The summary's source hashes match the supplied schematic and PCB.

The [enclosure validation report](../hardware/enclosure/validation.json) records valid CAD solids, **7 closed, manifold STL meshes** with no boundary/nonmanifold edges, and passing results for every modeled nominal intersection check. Checks include printed parts against each other and against the modeled module, connector and header envelopes.

Module dimensions, socket heights and component envelopes remain design assumptions. Purchased parts must be measured, sensor axes verified, and physical fit and printer tolerances checked. The PCB and enclosure have not been manufactured or assembled.

## Bench checklist

- [ ] Record the exact hardware revision, modules and wiring.
- [ ] Compile and flash the actual selected board.
- [ ] Confirm both I²C addresses and operation at 3.3 V.
- [ ] Log at rest before and after calibration.
- [ ] Check X and Y signs using motion in a known direction.
- [ ] Tilt the device to demonstrate the gravity limitation.
- [ ] Verify short noise spikes don't create repeated events.
- [ ] Power from USB without a serial terminal: hold for 1.5 seconds, release, calibrate, tap to start and tap to end.
- [ ] Confirm a hold never triggers a second short-press action on release; verify holds during a drive do not recalibrate.
- [ ] Check failed calibration, repeated start, recalibration and power-cycle behavior.
- [ ] Evaluate sample timing while refreshing the OLED.
- [ ] Power down, disconnect a sensor, restart, and confirm a clear error.
- [ ] With a current-limited bench supply and safe test wiring, interrupt only the IMU signal connection during a session; verify recording stops and the error persists. Restore power only after fixing wiring.
- [ ] Film a bench demo and publish only actual results.

Do vehicle tests only with a secure mount and a passenger managing the device. Review summaries while parked. This prototype gives no basis for judging emergency braking as a bad driving decision.

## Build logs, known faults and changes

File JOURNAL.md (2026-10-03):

# DriveDot — devlog

<!-- Generated by Half Life from project cmurr6oiu00zx01smbi1uyswa. Edits here are overwritten on the next sync. -->
<!-- Generated: 2026-10-03T15:06:51.197Z -->

> [!NOTE]
> This devlog is mirrored from [Half Life](https://halflife.hackclub.com). Editing it here will not change the platform's copy, and the next sync overwrites this file.

> A compact dashboard device that uses an IMU to measure acceleration, braking and cornering forces and gives drivers live visual feedback to help them drive more smoothly.

| Week | Tier | Hours logged | Entries |
| --- | --- | --- | --- |
| Warm-up | Tier 1 | 10h | 1 |

## Contents

1. [2026-10-03 — okay;](#2026-10-03-okay)

## Design

### 2026-10-03 — okay;

**10h**

okay;

i took a crap ton of time but i got drivedot from "idea" to files. the idea is a small usb powered dash

drivedot-01-assembled-case

drivedot-02-exploded-case

drivedot-03-case-interior

drivedot-04-schematic

drivedot-05-pcb-overview

drivedot-06-pcb-front

drivedot-07-pcb-back

drivedot-08-case-dimensions

drivedot-09-software-checks

drivedot-10-pcb-checks

 gadget that measures acceleration, braking, and cornering and shows how smooth it all is on a little screen. i want something i can actually build and use while i'm learning to drive.

the hardware is a seeed xiao esp32s3, an mpu6050 motion sensor, and a small 128×64 oled. the xiao is tiny enough to fit inside the case and has usb-c for power and uploading code. the screen and sensor share an i2c connection, and there's one button for calibration and recording sessions. running off usb means no battery and no tapping into the car's wiring, which was the point.

the pcb is a 60×40 mm carrier board. the xiao sits in sockets, and there are connections for the screen, sensor, and button. the screen and sensor mount separately and hook up with short wires, so the case layout has more wiggle room. the sensor needs to stay flat even if the screen ends up somewhere else in the case.

one thing to be careful about when assembling is the connector pin order. the screen connector goes ground then 3.3v, and the sensor connector goes 3.3v then ground, so they're opposite and not interchangeable. both are labeled on the board and the assembly instructions call it out, but still check the wires against the labels on the actual modules before plugging anything in.

there are also two optional resistor spots for the i2c pull-ups. i marked them to stay empty by default, since the breakout boards might already have resistors on them. i need to look at the real modules before deciding if anything goes there.

the enclosure is a body, a removable lid, a screen clamp, two sensor clamps, a button plunger, and a separate button cap. the main case is about 90×76×34.4 mm, with the button sticking up a bit past that. it has four mounting points for the pcb and an opening for the usb cable. the screen sits behind a window in the lid and the sensor gets its own flat mount in the bottom.

a few mechanical problems came up in the design review and got fixed. some of the early clamp shapes overlapped other parts. the sensor supports had to move so they weren't sitting under the soldered header pins. the screen clamp needed room for its connector and wires. the usb opening had to be adjusted for the height of the xiao and its sockets. but these are all fixes to the computer model so far, so they still need checking with real parts.

the button has a guide and a travel stop now too. the printed plunger reaches down to the switch on the pcb, and the cap limits how far it can move. the actual switch height matters a lot here, so that's another measurement to take before i call the case dimensions final.

holding the button for 1.5 seconds and letting go starts calibration while the device is idle. after calibration, a short press starts a session and another short press ends it. letting go after a long hold shouldn't accidentally start recording. it shows forward and sideways acceleration, a moving dot, and a summary when the session ends. it also spits out csv over usb so i can look at the readings during bench testing. there are checks for failed sensor reads and bad calibration samples now, but those error cases haven't been tried on real electronics.

the automated results are a decent starting point. the firmware builds for the xiao board, and the motion, button, and calibration tests pass. the pcb checks report no electrical-rule or layout-rule violations and nothing unconnected. all seven printable parts have closed meshes, and the modeled fit checks pass. but that only checks the files and the software logic. it can't tell me if a module that shows up is a slightly different size, or if a printed part actually fits.

the repo has the editable kicad files, fabrication exports, stl files, step files, renders, and assembly instructions. the images attached are the assembled case render, an exploded view showing the inside, and the pcb layout.

the budget isn't finished. i have supplier listings for the main electronics, but connectors, screws, printing, pcb fabrication, shipping, and tax still need to be added up yk

next up is measuring the real components, going through the wiring, and testing the electronics on a bench before anything goes in the case. after that i can print the enclosure and check screen clearance, usb access, button movement, and whether the sensor mount is solid. so for now drivedot has a first set of design files, and the physical building and testing is still ahead!



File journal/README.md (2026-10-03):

# DriveDot journal

No design hours have been logged in this scaffold.

Create one entry per actual work session using the template below. Include what you learned, screenshots, mistakes and changes. Keep real elapsed time; check the event rules before counting AI-assisted work. Do not retroactively invent sessions to meet a threshold.

## Entry template

### YYYY-MM-DD — What I worked on

- **Actual duration:**
- **Goal:**
- **What I did myself:**
- **Tools / AI assistance used:**
- **What worked and what failed:**
- **Design decision and why:**
- **Evidence:** link to screenshots, source files, commits or measurements
- **Next step:**

For this repository's initial setup: an AI assistant generated starter documentation, firmware, tests and CI configuration. Review and understand those files before using them as the foundation of your own design work.

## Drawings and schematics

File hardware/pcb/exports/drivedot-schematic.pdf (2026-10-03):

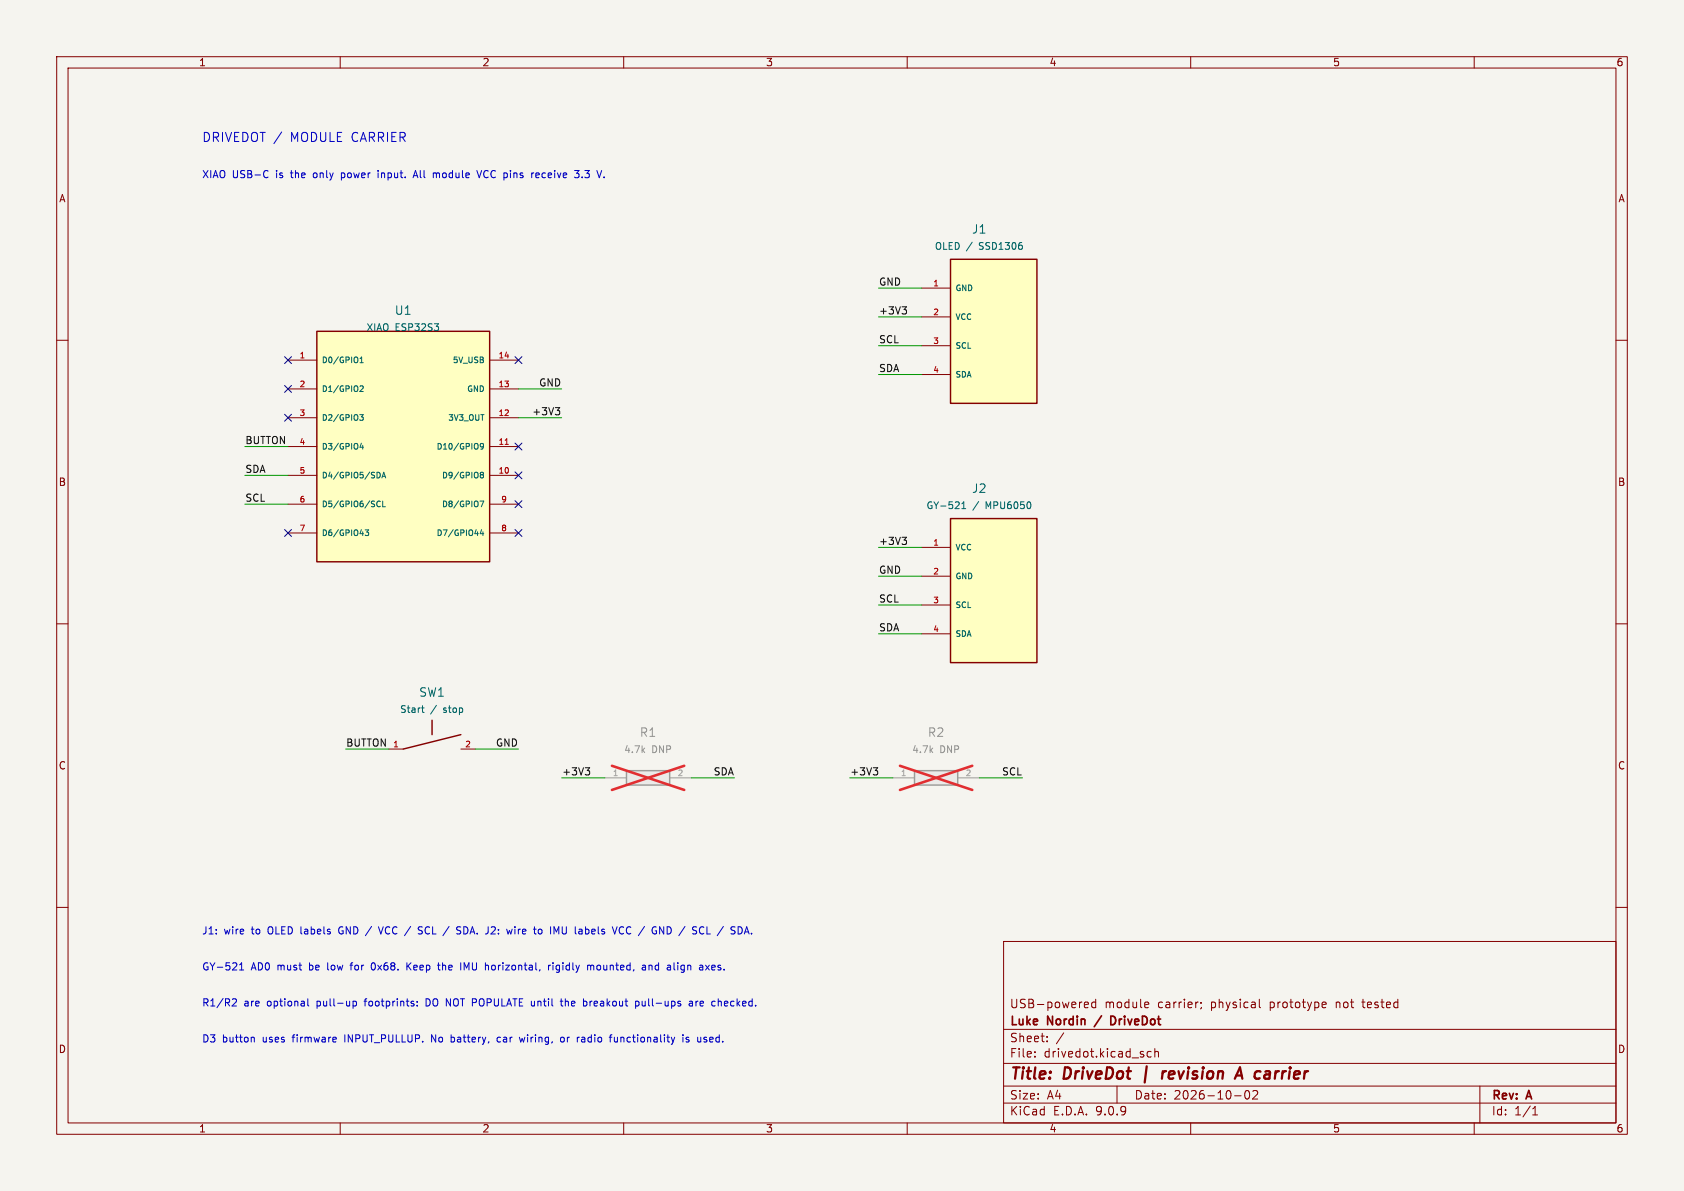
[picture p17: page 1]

XIAO USB-C is the only power input. All module VCC pins receive 3.3 V. DRIVEDOT / MODULE CARRIER
XIAO ESP32S3

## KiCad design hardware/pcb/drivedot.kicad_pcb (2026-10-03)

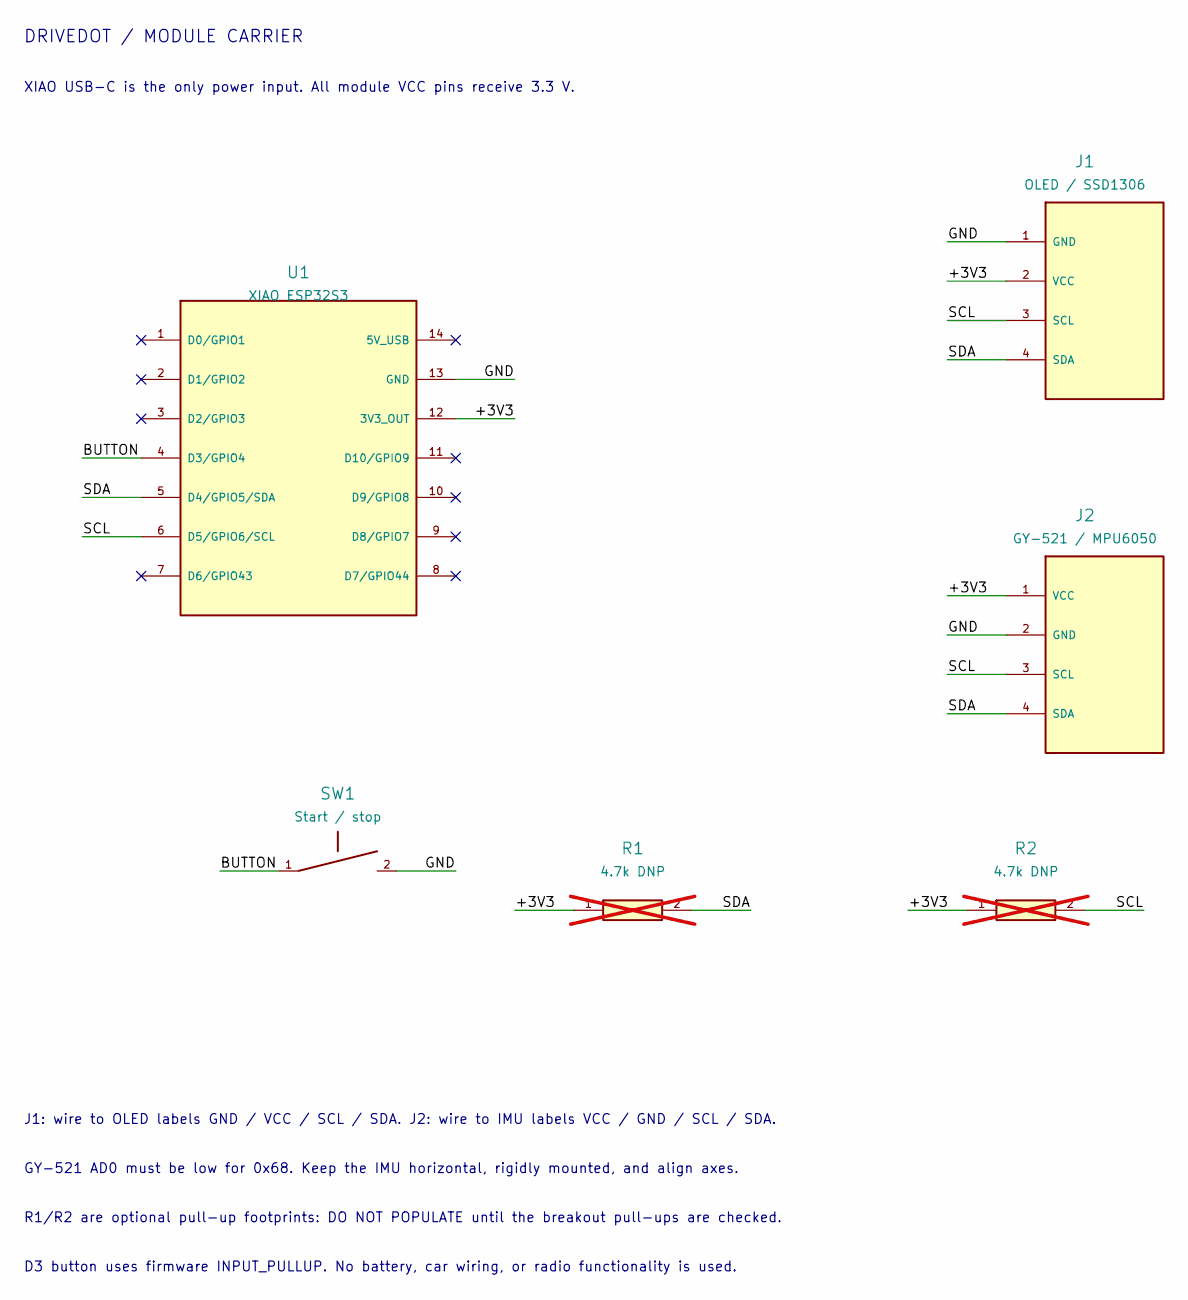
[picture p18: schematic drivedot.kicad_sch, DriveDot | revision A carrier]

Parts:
J1: OLED / SSD1306; Header_1x04
J2: GY-521 / MPU6050; Header_1x04
R1, R2: 4.7k DNP; R_Axial_P7.62; not fitted
SW1: Start / stop; Tactile_6mm
U1: XIAO ESP32S3; XIAO_Socket

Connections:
/+3V3: J1.2 (VCC), J2.1 (VCC), R1.1, R2.1, U1.12 (3V3_OUT)
/BUTTON: SW1.1, U1.4 (D3/GPIO4)
/GND: J1.1 (GND), J2.2 (GND), SW1.2, U1.13 (GND)
/SCL: J1.3 (SCL), J2.3 (SCL), R2.2, U1.6 (D5/GPIO6/SCL)
/SDA: J1.4 (SDA), J2.4 (SDA), R1.2, U1.5 (D4/GPIO5/SDA)

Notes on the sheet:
DRIVEDOT / MODULE CARRIER
XIAO USB-C is the only power input. All module VCC pins receive 3.3 V.
J1: wire to OLED labels GND / VCC / SCL / SDA. J2: wire to IMU labels VCC / GND / SCL / SDA.
GY-521 AD0 must be low for 0x68. Keep the IMU horizontal, rigidly mounted, and align axes.
R1/R2 are optional pull-up footprints: DO NOT POPULATE until the breakout pull-ups are checked.
D3 button uses firmware INPUT_PULLUP. No battery, car wiring, or radio functionality is used.

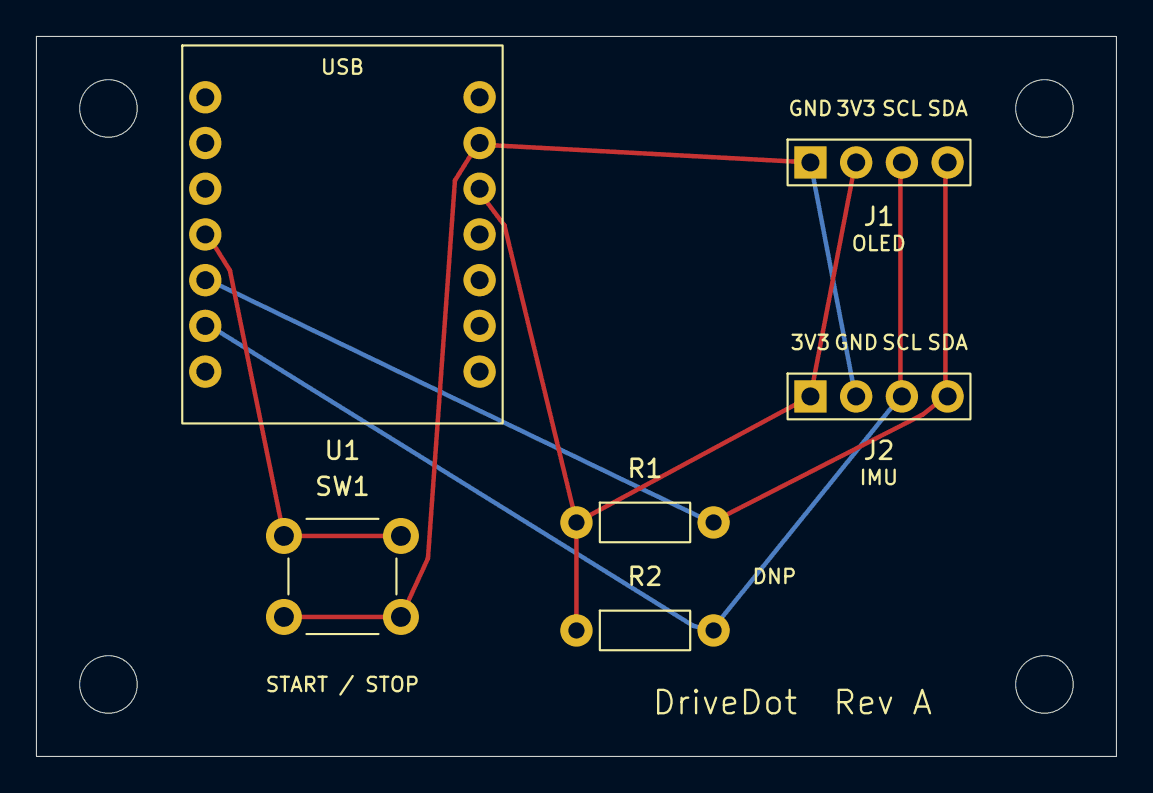
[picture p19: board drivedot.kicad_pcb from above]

Board: 2 copper layers, 60.0 x 40.0 mm, 10 parts (0 on the bottom side), 5 nets.

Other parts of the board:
H1, H2, H3, H4: M3; MountingHole_M3

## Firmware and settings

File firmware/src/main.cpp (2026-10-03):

#include <Arduino.h>
#include <Wire.h>
#include <Adafruit_MPU6050.h>
#include <Adafruit_SSD1306.h>
#include "config.h"
#include "motion.h"
#include "button.h"
#include "calibration.h"

Adafruit_MPU6050 imu;
Adafruit_SSD1306 display(128, 64, &Wire, -1, 400000, 400000);
drivedot::Motion motion;
drivedot::Button button;
bool displayReady = false, imuReady = false, hasSession = false;
bool calibrationPending = false;
uint32_t lastSample = 0, lastDisplay = 0;

void message(const char* first, const char* second) {
  Serial.printf("# %s: %s\n", first, second);
  if (!displayReady) return;
  display.clearDisplay(); display.setTextSize(1); display.setCursor(0, 8);
  display.println(first); display.println(); display.println(second);
  display.display();
}

// MPU6050 getEvent() in the pinned Adafruit release always returns true.
// Check the actual I2C transaction and byte count instead of trusting it.
bool readRegisters(uint8_t reg, uint8_t* bytes, size_t length) {
  Wire.beginTransmission(config::IMU_ADDRESS);
  Wire.write(reg);
  if (Wire.endTransmission(false) != 0) return false;
  const size_t received = Wire.requestFrom(config::IMU_ADDRESS, length, true);
  if (received != length) {
    while (Wire.available()) Wire.read();
    return false;
  }
  for (size_t i = 0; i < length; ++i) {
    const int value = Wire.read();
    if (value < 0) return false;
    bytes[i] = static_cast<uint8_t>(value);
  }
  return true;
}

bool configurationMatches() {
  uint8_t ranges[3], power;
  // CONFIG=21 Hz, GYRO_CONFIG=500 deg/s, ACCEL_CONFIG=4 g.
  return readRegisters(0x1A, ranges, sizeof(ranges)) &&
      readRegisters(0x6B, &power, 1) && (ranges[0] & 7) == 4 &&
      (ranges[1] & 0xF8) == 8 && (ranges[2] & 0xF8) == 8 &&
      (power & 0xC0) == 0;
}

bool readSample(drivedot::Sample& sample) {
  uint8_t bytes[14];
  if (!readRegisters(0x3B, bytes, sizeof(bytes))) return false;
  const auto axis = [&bytes](size_t index) -> float {
    const uint16_t raw = (static_cast<uint16_t>(bytes[index]) << 8) |
                         bytes[index + 1];
    const int32_t signedRaw = raw >= 0x8000 ? static_cast<int32_t>(raw) - 65536 : raw;
    return static_cast<float>(signedRaw);
  };
  // Fixed scales match the configuration read back at boot and calibration.
  constexpr float accelScale = drivedot::GRAVITY / 8192.0f;
  constexpr float gyroScale = 0.01745329252f / 65.5f;
  sample = {axis(0) * accelScale, axis(2) * accelScale, axis(4) * accelScale,
            axis(8) * gyroScale, axis(10) * gyroScale, axis(12) * gyroScale};
  return true;
}

void endSession() {
  if (!motion.active()) return;
  motion.stop();
  const auto& s = motion.summary;
  Serial.printf("# Summary: %.1fs, score=%d, peak=%.2fg, accel=%lu, brake=%lu, turn=%lu\n",
      s.seconds, s.seconds > 0 ? s.score() : -1, s.peakG, static_cast<unsigned long>(s.accelerationEvents),
      static_cast<unsigned long>(s.brakingEvents), static_cast<unsigned long>(s.turningEvents));
}

void sensorFault() {
  endSession();
  imuReady = false;
  calibrationPending = false;
  message("SENSOR ERROR", "Check wiring; reboot");
}

bool calibrate() {
  if (!imuReady || motion.active()) return false;
  motion.clearCalibration();  // A failed retry must not retain an old mount offset.
  hasSession = false;
  button.suppressRelease();
  message("CALIBRATING", "Keep flat/still 2s");
  delay(300);  // Allow the released button and mount to settle.
  if (!configurationMatches()) { sensorFault(); return false; }
  drivedot::Calibration calibration;
  uint32_t previous = millis();
  for (int i = 0; i < 100; ++i) {
    while (millis() - previous < config::SAMPLE_MS) delay(1);
    drivedot::Sample sample;
    if (!readSample(sample)) { sensorFault(); return false; }
    const uint32_t sampledAt = millis();
    // Do not accept a calibration that was substantially stalled.
    if (sampledAt - previous > 100 || !calibration.add(sample)) {
      message("CALIBRATION FAILED", "Hold 1.5s to retry"); return false;
    }
    previous = sampledAt;
  }
  if (!calibration.valid()) {
    message("KEEP FLAT AND STILL", "Hold 1.5s to retry"); return false;
  }
  motion.calibrate(calibration.x(), calibration.y());
  lastSample = millis();
  message("READY", "Tap button to start");
  return true;
}

void startSession() {
  if (motion.active() || calibrationPending) return;
  if (!motion.calibrated()) {
    message("CALIBRATE FIRST", "Park; hold 1.5s"); return;
  }
  motion.start(); hasSession = true;
  lastSample = millis();
  Serial.println("# Session started");
}

void render() {
  if (!displayReady || !motion.calibrated() || calibrationPending) return;
  display.clearDisplay(); display.setTextSize(1); display.setCursor(0, 0);
  if (!motion.active()) {
    display.println(hasSession ? "DRIVE SUMMARY" : "DRIVEDOT / READY");
    if (hasSession) {
      const auto& s = motion.summary;
      if (s.seconds > 0) {
        display.printf("%.0fs  Smoothness %d\nPeak %.2fg\nAccel %lu / Brake %lu\nTurns %lu\n",
            s.seconds, s.score(), s.peakG, static_cast<unsigned long>(s.accelerationEvents),
            static_cast<unsigned long>(s.brakingEvents), static_cast<unsigned long>(s.turningEvents));
      } else display.println("No samples recorded");
    } else {
      display.println("Mounted flat + still");
      display.println("Tap to start");
    }
    display.setCursor(0, 48); display.print("Hold 1.5s: calibrate");
    display.setCursor(0, 56); display.print("Tap: new session");
  } else {
    display.print("DRIVEDOT");
    display.setCursor(0, 18); display.printf("F %+.2fg\nL %+.2fg", motion.forwardG, motion.lateralG);
    display.setCursor(0, 44);
    if (motion.summary.seconds > 0) display.printf("Score %d", motion.summary.score());
    else display.print("Score --");
    display.setCursor(0, 56); display.print("Tap: end");
    display.drawRect(82, 17, 44, 44, SSD1306_WHITE);
    display.drawLine(104, 19, 104, 58, SSD1306_WHITE);
    display.drawLine(84, 39, 123, 39, SSD1306_WHITE);
    // Leftward acceleration goes left; forward acceleration goes down.
    const int dx = std::max(-19, std::min(19, static_cast<int>(-motion.lateralG * 38)));
    const int dy = std::max(-19, std::min(19, static_cast<int>(motion.forwardG * 38)));
    display.fillCircle(104 + dx, 39 + dy, 2, SSD1306_WHITE);
  }
  display.display();
}

void setup() {
  Serial.begin(115200);
  pinMode(config::BUTTON_PIN, INPUT_PULLUP);
  Wire.begin(config::SDA_PIN, config::SCL_PIN);
  Wire.setClock(400000);
  Wire.setTimeOut(50);
  Wire.beginTransmission(config::OLED_ADDRESS);
  const bool oledAck = Wire.endTransmission() == 0;
  displayReady = oledAck && display.begin(SSD1306_SWITCHCAPVCC, config::OLED_ADDRESS);
  if (displayReady) { display.setTextColor(SSD1306_WHITE); display.setTextWrap(false); }
  else Serial.println("# OLED not found; check wiring / 0x3C");
  imuReady = imu.begin(config::IMU_ADDRESS, &Wire);
  if (!imuReady) { message("IMU NOT FOUND", "Check wiring / 0x68"); return; }
  imu.setAccelerometerRange(MPU6050_RANGE_4_G);
  imu.setGyroRange(MPU6050_RANGE_500_DEG);
  imu.setFilterBandwidth(MPU6050_BAND_21_HZ);
  if (!configurationMatches()) { sensorFault(); return; }
  Serial.println("# Hold button 1.5s and release to calibrate while parked; tap to start/end");
  Serial.println("# Commands: c calibrate, n new session, e end");
  Serial.println("ms,forward_g,lateral_g,score,active");
  message("PARK + MOUNT FLAT", "Hold button 1.5s");
  lastSample = millis();
}

void loop() {
  if (!imuReady) { delay(20); return; }
  if (Serial.available()) {
    const char command = Serial.read();
    if (command == 'c' && !motion.active()) {
      calibrationPending = false;
      calibrate(); lastSample = millis();
    } else if (command == 'n') startSession();
    else if (command == 'e') endSession();
    if (!imuReady) return;
  }
  const auto event = button.update(digitalRead(config::BUTTON_PIN) == LOW, millis());
  if (event == drivedot::ButtonEvent::LongPress && !motion.active()) {
    calibrationPending = true;
    message("RELEASE BUTTON", "Then keep flat/still");
  } else if (event == drivedot::ButtonEvent::ShortPress && !calibrationPending) {
    if (motion.active()) endSession(); else startSession();
  }
  if (calibrationPending && !button.pressed()) {
    calibrationPending = false;
    calibrate(); lastSample = millis();
    if (!imuReady) return;
  }
  // Refresh now after any blocking calibration, avoiding unsigned time underflow.
  if (millis() - lastSample >= config::SAMPLE_MS && !calibrationPending) {
    drivedot::Sample sample;
    if (!readSample(sample)) { sensorFault(); return; }
    const uint32_t sampledAt = millis();
    const float dt = (sampledAt - lastSample) / 1000.0f;
    lastSample = sampledAt;
    if (motion.update(sample.x, sample.y, dt, config::FORWARD_SIGN, config::LATERAL_SIGN)) {
      Serial.printf("%lu,%.3f,%.3f,%d,%d\n", static_cast<unsigned long>(sampledAt),
          motion.forwardG, motion.lateralG,
          motion.summary.seconds > 0 ? motion.summary.score() : -1, motion.active());
    }
  }
  const uint32_t now = millis();
  if (now - lastDisplay >= config::DISPLAY_MS) { lastDisplay = now; render(); }
  delay(1);
}

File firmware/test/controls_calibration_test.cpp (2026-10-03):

#include <cassert>
#include <cmath>
#include <iostream>
#include <limits>
#include "button.h"
#include "calibration.h"

using drivedot::ButtonEvent;

void testButton() {
  drivedot::Button button;
  assert(button.update(true, 10) == ButtonEvent::None);
  assert(button.update(false, 20) == ButtonEvent::None); // Contact bounce.
  assert(button.update(true, 25) == ButtonEvent::None);
  assert(button.update(true, 60) == ButtonEvent::None);
  assert(button.pressed());
  assert(button.update(false, 120) == ButtonEvent::None);
  assert(button.update(true, 130) == ButtonEvent::None); // Release bounce.
  assert(button.update(false, 140) == ButtonEvent::None);
  assert(button.update(false, 175) == ButtonEvent::ShortPress);
  assert(!button.pressed());
  assert(button.update(false, 1000) == ButtonEvent::None);

  assert(button.update(true, 2000) == ButtonEvent::None);
  assert(button.update(true, 2035) == ButtonEvent::None);
  assert(button.update(true, 3534) == ButtonEvent::None);
  assert(button.update(true, 3535) == ButtonEvent::LongPress);
  assert(button.update(true, 5000) == ButtonEvent::None); // Never repeat.
  assert(button.update(false, 5010) == ButtonEvent::None);
  assert(button.update(false, 5045) == ButtonEvent::None); // No accidental start.
  assert(!button.pressed());

  // A delayed loop that first sees release after the threshold still means hold.
  assert(button.update(true, 6000) == ButtonEvent::None);
  assert(button.update(true, 6035) == ButtonEvent::None);
  assert(button.update(false, 8000) == ButtonEvent::None);
  assert(button.update(false, 8035) == ButtonEvent::LongPress);

  // millis() wraps about every 49 days; durations use unsigned subtraction.
  drivedot::Button wrap;
  const uint32_t begin = UINT32_MAX - 100;
  assert(wrap.update(true, begin) == ButtonEvent::None);
  assert(wrap.update(true, begin + 35) == ButtonEvent::None);
  assert(wrap.update(true, begin + 1535) == ButtonEvent::LongPress);
  assert(wrap.update(false, begin + 1600) == ButtonEvent::None);
  assert(wrap.update(false, begin + 1635) == ButtonEvent::None);

  drivedot::Button serial;
  serial.update(true, 1); serial.update(true, 36);
  serial.suppressRelease();
  serial.update(false, 100);
  assert(serial.update(false, 135) == ButtonEvent::None);
}

void testCalibration() {
  const drivedot::Sample atRest = {0.1f, -0.2f, drivedot::GRAVITY, 0.01f, 0, 0};
  drivedot::Calibration good;
  for (int i = 0; i < 99; ++i) assert(good.add(atRest));
  assert(!good.valid());
  assert(good.add(atRest)); assert(good.valid());
  assert(std::fabs(good.x() - 0.1f) < 0.0001f);
  assert(std::fabs(good.y() + 0.2f) < 0.0001f);

  drivedot::Calibration zero, upsideDown, tilt, rotating, shakingZ, nonfinite;
  for (int i = 0; i < 100; ++i) {
    zero.add({0, 0, 0, 0, 0, 0});
    upsideDown.add({0, 0, -drivedot::GRAVITY, 0, 0, 0});
    tilt.add({0.5f * drivedot::GRAVITY, 0, 0.866f * drivedot::GRAVITY, 0, 0, 0});
    rotating.add({0, 0, drivedot::GRAVITY, 0, 0.11f, 0});
    shakingZ.add({0, 0, drivedot::GRAVITY + (i % 2 ? 0.3f : -0.3f), 0, 0, 0});
    nonfinite.add(atRest);
  }
  assert(!zero.valid() && !upsideDown.valid() && !tilt.valid());
  assert(!rotating.valid() && !shakingZ.valid());
  auto broken = atRest;
  broken.gz = std::numeric_limits<float>::quiet_NaN();
  assert(!nonfinite.add(broken) && !nonfinite.valid());
}

int main() {
  testButton(); testCalibration();
  std::cout << "Controls/calibration tests passed: debounce, tap/hold, release suppression, clock wrap, rest/tilt/motion/invalid data\n";
}

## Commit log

2026-10-03 Revise README for clarity and project status
    Updated the README to clarify project details and current status.
2026-10-03 Source DriveDot core parts and align wiring and firmware with XIAO ESP32S3
    [bom.csv]
2026-10-03 Add revision A PCB, printable enclosure and standalone button controls
    [body.step, body.stl, bom.csv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]
2026-10-03 Revise parts update and budget in READMEREADME: note switch to solder-free Atom Matrix parts list
    Updated parts list and budget details for revision a and Atom Matrix version.
2026-10-04 Revise planned components and update parts listREADME: update budget for original parts list, add planned led strip
    Updated the planned components and parts list details for the project.
2026-10-04 README: add LED strip to parts list, update total
    Updated the planned features and adjusted the parts list cost.
2026-10-05 README: enclosure and screws added, total $63.99 for tier 2
    Updated planned features and revised parts list costs.
2026-10-05 Add sourcing screenshots (print quote, PCB quote, shipping options, DigiKey cart)
